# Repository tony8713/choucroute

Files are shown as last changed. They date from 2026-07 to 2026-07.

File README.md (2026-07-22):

# earbox

*l'oreille de la maison* — a 24/7-listening home device that turns ambient
speech into your private, searchable memory, queried through the agent you
already use. **Raw audio never leaves the home.**

Listen → transcribe **locally** → write text into a git-backed memory → ask your
agent about your day over Telegram/WhatsApp. No audio is ever stored or sent.

## Architecture (two-tier)

- **Founder unit (v1): one box** = a **Jetson Orin Nano Super** brain + a
  **reSpeaker XMOS XVF3800** USB 4-mic array (on-chip beamforming/NS/AEC/AGC).
  The mic plugs into the Orin over USB; the Orin transcribes on its GPU with
  **faster-whisper** (CUDA int8) and writes text to a local git memory. **No
  network.**
- **Optional multi-room:** cheap **Pi 4 satellites** stream other rooms to the
  Orin over an **encrypted LAN hop** (TLS). Satellites keep zero storage.

Full design + privacy invariants: `docs/architecture.md`.

## Repo layout

```
orin/        the brain: orind.py (direct XVF3800 OR lan satellite server),
             capture.py (USB mic), stt.py (faster-whisper CUDA / whisper.cpp),
             denoise.py (optional, default-OFF), provision.sh (JetPack 6.x),
             gen_certs.sh, systemd/, config.example.toml
satellite/   optional Pi tier: satellited.py (capture→VAD→opus→TLS, zero
             storage), provision.sh (Pi OS Lite), systemd/, config.example.toml
common/      shared source of truth: earbox_core.py (VAD, cleaning, git memory,
             mute, delete-in-finally), wire.py (LAN protocol+TLS), codec.py
daemon/      summarize.py (text-only egress), query.py, and earboxd.py (the D1
             single-box legacy daemon), harness.py (D1 single-segment harness)
docs/        architecture.md
harness_twotier.py   prove the FULL two-tier plumbing on a Mac (below)
```

## Prove the two-tier plumbing on a Mac (no Pi, no Orin)

`harness_twotier.py` runs the **real** Orin daemon (`orin/orind.py`) in `lan`
mode with real self-signed TLS, then streams a wav through a loopback
"satellite" over the real TLS socket, using the exact wire framing + codec the
Pi uses. The Orin decodes each segment in tmpfs → transcribes → commits to git →
deletes the audio.

```bash
python3 harness_twotier.py scratch/test_fr.wav --seconds 30 --codec pcm
```

It uses the `whisper_cli` STT backend (whisper.cpp, needs `whisper-cli` + a ggml
model on PATH) because faster-whisper needs the Orin's CUDA. So it proves the
whole chain **except** faster-whisper itself, which is benchmarked on the device
(D3). Expect: `TWO-TIER PLUMBING: WORKED`, transcript committed, `stray audio: 0`.

The D1 single-box harness still works too: `cd daemon && python3 harness.py <wav>`.

## Deploy

**Founder unit (Orin + XVF3800), JetPack 6.x:**
```bash
sudo EARBOX_MODE=direct bash orin/provision.sh   # UNTESTED-ON-TARGET (no Orin in dev)
```
Then `arecord -l` to find the reSpeaker card and set `usb_capture_device` /
`usb_asr_channel` in `~/.config/earbox/orin.toml`.

Provision installs the live tree as the **earbox user's own git clone** at
`~earbox/earbox` (with an earbox-owned venv at `~earbox/earbox/venv`) and points
`/opt/earbox` at it via a symlink, so the systemd unit paths still resolve but
the code + venv are user-owned and git-updatable.

### Update the box (no sudo)

Code updates need **no root**. As the `earbox` user on the Orin:
```bash
cd ~/earbox && git pull && earbox-restart
```
`earbox-restart` just kills the daemon (`pkill -f orin/orind.py`); the unit has
`Restart=always`, so systemd relaunches `orind` on the new code in ~3s. No
`sudo rsync` to `/opt`, no `systemctl restart`. (New pip deps: same, just
`~/earbox/venv/bin/pip install ...` as the earbox user.)

### One-time migration (root, only if the box was provisioned the OLD way)

A box already running from a root-owned `/opt/earbox` copy is switched to the
user-repo layout once, with root, then never again:
```bash
sudo systemctl stop orind
sudo mv /opt/earbox /opt/earbox.bak                                   # keep the old copy as backup
sudo -u earbox git clone https://github.com/tony8713/choucroute.git /home/earbox/earbox  # if not already present
sudo -u earbox python3 -m venv /home/earbox/earbox/venv               # earbox-owned venv inside the clone
sudo -u earbox /home/earbox/earbox/venv/bin/pip install --upgrade pip
sudo -u earbox /home/earbox/earbox/venv/bin/pip install faster-whisper zeroconf
sudo ln -sfn /home/earbox/earbox /opt/earbox                          # unit's /opt/earbox/{orin,venv} now resolve into the clone
sudo install -Dm755 /home/earbox/earbox/orin/earbox-restart /usr/local/bin/earbox-restart
sudo systemctl start orind
```
The unit is untouched: `/opt/earbox/orin/orind.py` and
`/opt/earbox/venv/bin/python3` resolve through the symlink into the earbox-owned
clone. After this, every future update is the sudo-free `git pull` above.

**Optional Pi 4 satellite, Pi OS Lite (64-bit):**
```bash
sudo bash orin/provision.sh with EARBOX_MODE=lan on the Orin   # enables the TLS server + certs
sudo bash satellite/provision.sh                               # on the Pi
scp earbox@<orin>:/opt/earbox/tls/orin.crt /opt/earbox/tls/    # pin the Orin cert
# set satellite_id + orin_host (or leave empty for mDNS), then enable the unit
```

## Privacy in one line

Raw audio lives only in tmpfs and is deleted in a `finally` after each segment;
the founder unit opens no network at all; the optional satellite hop is TLS and
LAN-only; only a separate daily **text** summary may ever touch the network. Full
invariant table in `docs/architecture.md` §5.

## Status

Early, local-first, and moving fast. The capture → local-transcribe → git-memory
pipeline is validated end-to-end; the enclosure, fleet, and golden-image work
(D6) are in progress.

## License

MIT — see [LICENSE](LICENSE).

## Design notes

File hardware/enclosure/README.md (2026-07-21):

# earbox — founder-unit enclosure v1 ("le boitier")

Two-chamber tower housing the **NVIDIA Jetson Orin Nano Super Developer Kit**
(lower, vented chamber) and the **Seeed reSpeaker XVF3800 USB 4-mic array**
(upper chamber, kept in its **stock retail case** for v1). Generated with
[text-to-cad](https://github.com/earthtojake/text-to-cad) / build123d.

> **v1 scope:** keep the reSpeaker in its factory case (mic geometry preserved,
> simplest path). A bare-board v2 that reproduces the 66 mm mic square can come
> later. Every model dimension is a named variable at the top of
> `earbox_v1.py`; the acoustically-critical ones are one-line adjustable.

---

## v4 — "le cube" (CURRENT, printable)

Laurent's v4 refinements over v3. Files: `earbox_v4.py`, `earbox_v4.step`,
`earbox_v4.stl`, `preview_v4.png`.

- **Perfect cube** — 114.5 × 114.5 × 114.5 mm (+5 mm feet). Side = smallest the
  round 107 mm case allows while fitting Orin + plenum below the crown.
- **Flat top** — the v3 diagonal summit is gone.
- **Debossed "earbox" fixed** — was upside-down in v3 (`x_dir`/`z_dir` put local
  Y at −Z). Now upright and readable when the cube sits on its feet.
- **Triangles packed closer** — same rounded-triangle quincunx, tighter pitch:
  5×5 facing the Orin fan + a denser underside mesh.
- **No cable channel / clips / hole.** The reSpeaker case seats **rotated 45°**
  so its USB points into the box interior toward the (+X,+Y) corner; the cable
  just drops inside to the Orin. Only a **connector-clearance cutout** at that
  corner (through the cup wall + down through the deck) and a **triangular rim
  marker** on the top show how to orient the case.
- Kept: two-part corner-post pry joint (single solids, nothing captive), case
  **107 × 17 VERIFIED** + **0.75** fits, foam seat, **16 mm** mute hole, 4
  triangular **5 mm feet**, **3 mm** shell, support-light print orientation.

Verified by rendering the exported **STL** (not the sketch): cube, flat top,
upright text, clean rounded-triangle quincunx vents, and the corner cutout.

---

## v3 — "le monolithe vertical" (superseded by v4)

Laurent rejected v2 (vents rendered as hearts/stars; didn't read vertical).
v3 follows his literal spec. Files: `earbox_v3.py`, `earbox_v3.step`,
`earbox_v3.stl`, `preview_v3.png`.

- **Rectangular box, height largest** — 114.5 × 114.5 × **211 mm** (incl. 5 mm
  feet); height is the largest dimension. Orin flat at the bottom, tall plenum,
  reSpeaker crown on top.
- **Shell 3 mm.**
- **Diagonally truncated summit** — two same-side offset 45°-ish planar cuts
  (*deux outils légèrement décalés*) → a stepped/faceted diagonal top.
- **Ventilation = rounded-triangle QUINCONCE** (staggered rows, half-pitch
  offset, alternating up/down, webbed so triangles never touch): a **5×5 grid
  facing the Orin fan** (−X wall, low) + an **underside mesh** (floor intake).
  No other wall perforation. **Built as explicit 3-point polygons with corner
  fillets — not `RegularPolygon`/glyphs** (that + filleting overlapping
  triangles was the v2 hearts/stars bug).
- **4 triangular feet, 5 mm** high, under the corners.
- **"earbox" debossed 2 mm**, monospace (Menlo).

**Kept:** two-part easy-open split; case **107 × 17 VERIFIED**; **0.75 mm** on
all fits; foam-decoupled seat; Orin **30 mm** conservative; **16 mm** mute hole;
support-light orientation.

**The split / openability:** `mono_base` (tall vented body, holds Orin) +
`mono_crown` (truncated cup, holds cased reSpeaker). Four **corner posts** fused
into the base corners locate matching **blind holes** in the crown — 0.75 mm
slip fit. Crown lifts straight off / pries with a fingernail; **nothing captive,
no screws.** Both parts are single watertight solids. Lift crown → base open on
top → drop the Orin in.

**Print orientation (support-light):** `mono_base` upright, open-top up (feet
on the plate, triangle holes + I/O bridge as wall openings); `mono_crown` cup-up
(deck on the plate; cup opens up; the diagonal summit facets step inward =
self-supporting; post holes are shallow bottom pockets).

**Verification:** vents, summit, feet, and text were all confirmed by rendering
the **exported STL** (orthographic outer-skin projections), not the sketch —
the triangles are clean rounded triangles en quinconce, no hearts/stars.

**Same fundamental conflict, resolved:** the round 107 mm case forces a
~114.5 mm footprint in both axes, so "narrow" is read as **proportion** — a
114.5 × 211 tall monolith (ratio 1.84), not a wider box.

---

## v2 — "le monolithe" (superseded by v3)

Laurent rejected v1 as *"batiment antique"* (too temple-like). v2 adopts his
design language. Files: `earbox_v2.py`, `earbox_v2.step`, `earbox_v2.stl`,
`preview_v2.png`.

**Design language (Laurent):**
- **Vertical monolith** — 128.5 × 128.5 × 184 mm, height:width ≈ **1.43** (v1
  was 0.56, a squat tower). Tall exhaust-plenum body over the Orin chamber.
- **Sommet tronqué sur deux arêtes** — the two top edges (‖ X) are truncated
  with 45° planar cuts (8 mm), a chiselled crown; the round mic opening sits in
  the middle of it.
- **Triangle-mesh ventilation** — tessellated up/down rounded triangles (11 mm
  side, 1.3 mm corner radius, 4 mm webs) instead of slots: floor intake + a high
  panel on all four walls (exhaust + the signature texture).

**Verified dims used:** reSpeaker case **107 mm × 17 mm** (caliper). Orin stack
height stays the conservative **30 mm** (still unverified).

**FDM fits (Laurent's 2am rule): 0.75 mm on ALL fits** — cup seat (Ø108.5 ID
around the 107 case, foam-lined), Orin chamber (generous), and the two-part
joint. Loose is shimmable with foam; tight is a trash print.

**Openability — the split (hard requirement):**
- **Two parts:** `mono_base` (tall vented body, holds the Orin) and
  `mono_crown` (truncated cup block, holds the cased reSpeaker).
- **Joint:** the base has an upstanding **locating spigot** (fused to the wall);
  the crown has a matching **groove** in its underside. The crown drops on and
  **lifts straight off** — 0.75 mm slip fit, pry with a fingernail, **nothing
  captive, no screws.** Both are single watertight solids.
- **Access:** lift the crown → the base is open on top → drop the Orin in (or
  out). The reSpeaker drops into the crown cup from the top. Fully serviceable.

**Print orientation (support-light):**
- `mono_base`: **upright, open-top up.** Vertical walls; the triangle holes and
  I/O windows bridge as wall openings; floor solid on the plate. No supports.
- `mono_crown`: **cup-up, deck on the plate.** Cup cavity opens upward (no
  support); the two 45° truncation facets step *inward* going up (self-
  supporting); the joint groove is a shallow bottom pocket (a few-mm bridge).

**Design-language conflicts and how they were resolved:**
1. *Deep two-edge truncation vs. a near-full-width mic cup.* The 107 mm case
   leaves almost no wall at the footprint edges, so a large bevel would breach
   the cup. **Resolved** by adding a 7 mm solid **joint frame** around the cup
   (footprint grows to 128.5), giving real material for both the bevel and the
   pry joint — at the cost of some slimness, recovered via **height** (1.43
   ratio). The 8 mm bevel now lives in the frame.
2. *"Slender footprint" vs. the round 107 mm cup.* A truly slim footprint is
   impossible while the cased mic sits on top. **Resolved** by reading "vertical"
   as **proportion, not plan area**: constant clean cross-section, tall body,
   truncated crown — a monolith, not a mushroom (no overhang, which would re-read
   as temple/pedestal).
3. *OCC chamfer failed at the rounded corners; pending-face extrude dropped the
   triangle sketch.* Engineering, not design: truncation done with **planar
   splits**, triangle panels extruded from an **explicit sketch**. Spigot made to
   **overlap** the wall so the base stays one fused solid.

Open items for Laurent are unchanged below (foam thickness/material, Orin stack
height, PSU — external **60 W barrel brick confirmed**, base↔crown retention if
the pry fit is too loose/tight after measuring).

## Files

| File | What |
| --- | --- |
| `earbox_v1.py` | Parametric build123d source. `gen_step()` returns the 2-part assembly (`orin_base` + `mic_tower`). |
| `earbox_v1.step` | Primary CAD artifact (assembly). |
| `earbox_v1.stl` | Printable mesh sidecar. |
| `foam_gasket.py` | 2D generator for the laser-cut foam decoupling ring. |
| `foam_gasket.dxf` | Laser-cut layout for Laurent (foam). |
| `preview.png` | Isometric preview render. |

Regenerate after editing dims:

```bash
# from tools/text-to-cad with its venv active, run against this dir
python skills/cad/scripts/step /Users/tony/work/earbox/hardware/enclosure/earbox_v1.py \
  --stl /Users/tony/work/earbox/hardware/enclosure/earbox_v1.stl
# or standalone: python earbox_v1.py  (writes earbox_v1.step)
python foam_gasket.py
```

## Architecture

```
            ___________________            <- reSpeaker mics face up, ~6 mm proud
           /   reSpeaker case  \           <- STOCK retail case (kept intact)
          | [ ]  mic  puck  [ ] |          <- LED ring band recessed near rim
          |=== foam gasket ring ===|       <- ONLY load path (laser-cut foam)
       ___|_______ deck __________|___     <- SOLID deck: isolates fan noise
      |    |  cable channel (USB)  |   |    <- one 9 mm pass-through, deck solid elsewhere
      |    +-------------------+    |  <-- mute switch hole (privacy) on cup wall
      |     Jetson Orin Nano Super   |
      |  [====== fan / heatsink ===] |     <- exhaust vents on 3 side walls (high)
      | O O   standoffs lift board   |     <- intake vents in the floor
      |__[I/O ports: DP USB USB RJ45 USB-C DC]__|  <- +Y long wall
```

- **Two chambers, acoustically decoupled.** The cased reSpeaker rests only on a
  laser-cut **foam gasket ring** seated in a recess in the cup floor; there is
  radial clearance (`RESPEAKER_RADIAL_CLEAR`, 1 mm) between the case and the cup
  wall, so there is **no rigid path** from the mic case to the chassis. The deck
  under the gasket is **solid** (except the cable channel), so the Orin fan's
  airborne noise is blocked from the mic chamber and the foam breaks the
  vibration path.
- **Real airflow for the Orin.** Intake slots in the floor (cool air drawn up
  under the lifted board), exhaust slots high on three side walls. `ORIN_LIFT`
  (4 mm) standoffs create an underside plenum. Nothing sits directly over the
  fan; `ORIN_TOP_CLEAR` (8 mm) leaves head-room above the fan to the deck.
- **Cable channel.** A single 9 mm channel through the deck routes the USB-C
  from the reSpeaker down to a USB-A port on the Orin.
- **I/O openings** on the +Y long wall: DisplayPort, 2× USB-A (double stack),
  RJ45, USB-C, DC barrel jack. The board registers against this wall so
  connectors align with the windows.
- **Privacy mute switch** hole on the cup wall (7 mm, panel-mount).
- **LED ring band**: shallow external recess near the cup's top rim where
  Fabien's trust-interface LED ring can later seat (depth < wall, non-breaching).

## Dimensions — VERIFIED vs UNVERIFIED

Per Laurent/Iris: online reSpeaker case dims diverge, so **every reSpeaker case
value below is UNVERIFIED and must be caliper-checked (or measured from Seeed's
official STEP) before printing.** VERIFIED = official datasheet/spec.

### Jetson Orin Nano Super Dev Kit (P3768 reference carrier)

| Dim | Value | Status | Source |
| --- | --- | --- | --- |
| Board L × W | 100 × 79 mm | **VERIFIED** | NVIDIA Orin Nano Dev Kit datasheet |
| Assembled height (incl. thermal) | **30 mm used** (datasheet says 21 mm "incl. feet, carrier, module, thermal"; jetsonhacks quotes 30 mm) | **UNVERIFIED / conflict** | NVIDIA datasheet vs jetsonhacks — we default to the larger 30 mm so the fan is never choked. Caliper the real Super fan; if ~21 mm set `ORIN_HEIGHT=21`. |
| DC barrel jack | 5.5 mm OD / 2.5 mm ID, centre-positive | **VERIFIED** | NVIDIA hardware_layout |
| USB-C (data) | 1× | **VERIFIED** | NVIDIA hardware_layout |
| I/O all on one long edge | DP → 2× USB-A stack (4 ports) → RJ45 → USB-C → DC jack | edge **VERIFIED** (photos); exact left→right order **UNVERIFIED** | NVIDIA hardware_layout + product photos |
| 40-pin GPIO header | opposite long edge | **UNVERIFIED** (standard P3768) | — |
| microSD | on the module underside | **VERIFIED** | NVIDIA callout |
| Mounting-hole pattern | not published | **UNVERIFIED** | pull from NVIDIA STEP or measure |
| Fan airflow | top axial fan, blows **down** through fins, exhausts laterally | type **VERIFIED**, vector **UNVERIFIED** | assembly type |

### Seeed reSpeaker XVF3800 (retail, in stock case)

| Dim | Value | Status | Source |
| --- | --- | --- | --- |
| PCB shape | circular | **VERIFIED** | Seeed wiki / product page |
| Bare PCB diameter | ~99 mm (× 4 mm thick) | **UNVERIFIED** | cnx-software (third-party) — note: brief said ~70 mm, actual is ~99 mm |
| Stock case outer diameter | **107 mm** | **VERIFIED** | Laurent caliper 2026-07-22 |
| Stock case height | **17 mm** | **VERIFIED** | Laurent caliper 2026-07-22 |
| Case shape | round | **VERIFIED** (shape only) | Seeed p-6490 page |
| Mic array geometry | 4 mics on a 66 mm square (diag ~93.3 mm, radius ~46.7 mm) | **VERIFIED** | Seeed wiki mic coordinates |
| USB | USB-C (UAC 2.0); 2nd USB-C for firmware | **VERIFIED** | Seeed wiki |
| Case SKU | with-case = p-6490 (base p-6488 is bare board) | **VERIFIED** | Seeed product pages |
| Mounting holes | not published | **UNVERIFIED** | measure STEP |

## Derived enclosure envelope (at current defaults)

| Quantity | Value |
| --- | --- |
| Base outer (L × W × H) | 111 × 110 × 45 mm |
| Mic tower (dia × H) | 110 mm × 17 mm |
| Overall height (base + tower + case proud) | ~68 mm |
| Wall / deck thickness | 3.0 mm |
| Cup inner dia (case + 2×clearance) | 104 mm |
| Foam gasket ring | OD 104 / ID 92 mm |

> The cased mic puck (~110 mm) is wider than the bare Orin footprint (~90 mm),
> so the base is grown to fully support the puck; the extra interior around the
> board is air plenum (helps, does not choke, the fan).

## Print notes

- FDM, 3 mm walls, no heroic supports intended. Print the **two parts
  separately**, each open-side-down:
  - `orin_base`: print floor-down; port windows and side vents print as wall
    openings (bridged), no supports needed.
  - `mic_tower`: print deck-down (cup opening up); the cup is a simple upward
    cavity — no supports. The LED band and mute hole are shallow/side features.
- Suggested: 0.2 mm layers, 3–4 perimeters, 20–30% infill (PETG or ASA for
  heat near the Jetson; PLA fine for a bench mock-up).
- Cable channel and mute hole may need a light chamfer/ream after printing.
- The two parts are a clearance stack in v1 (tower sits on the base rim). Add
  screw bosses / a lip catch in v2 once real parts are calipered.

## Foam gasket spec (for Laurent)

- **Part:** flat annular ring, laser-cut from foam.
- **OD:** 104 mm (= cup inner diameter; `CUP_INNER_DIA`).
- **ID:** 92 mm (open window under the mics; `FOAM_SEAT_INNER_DIA`).
- **Thickness:** **3 mm assumed — please confirm** (`FOAM_THICKNESS`). This sets
  both the gasket-seat recess depth and the mic stand-off, so the CAD updates
  with whatever foam stock you pick.
- **Material:** soft closed-cell (EVA / PORON / EPDM) for damping; final
  durometer your call.
- Layout: `foam_gasket.dxf`.

## Open questions for Laurent

1. **Foam thickness / material** for the gasket (drives seat depth + standoff).
2. **Real Orin Super stack height** incl. fan — 21 mm (datasheet) or ~30 mm
   (measured)? Sets `ORIN_HEIGHT` and the whole lower-chamber height.
3. **reSpeaker stock case** real OD + height (caliper) — sets the cup.
4. **PSU strategy:** barrel-jack brick external, or integrate a DC supply inside
   the base? v1 assumes external brick, barrel jack only.
5. Mounting: screw bosses vs clip lip between base and tower for v2.

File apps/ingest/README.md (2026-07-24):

# @choucroute/ingest — Fly audio-ingest API

A small Bun WebSocket server that accepts a **live binary audio stream** from the
earbox and measures it, exposing a clean seam where cloud STT (Parakeet/Canary on
a GPU) attaches next. Deployed on Fly.io in **region `sin`** (Singapore — closest
to the box in Thailand, UTC+7).

This reverses the earlier "audio never leaves the box" model. That is a deliberate
product decision (Less, 2026-07-23). The **irreversible flip of pointing the real
box at this endpoint is still pending Less + Laurent alignment** — this repo ships
the plumbing and a local/test client proof only; do not auto-start the box streamer
against prod.

## Audio format (the wire contract)

Raw **PCM S16LE, 16 kHz, mono** — exactly what `orin/capture.py` produces. Binary
WS frames of raw PCM, ~100 ms each (3200 bytes). Continuous 16k PCM ≈ **256 kbps**;
Opus would cut that ~10x and is the obvious next optimization (the box already has
`opusenc`; see `common/codec.py`). Start with PCM for simplicity.

## Endpoints

- `GET /health` → `{ status, uptimeSeconds, openConnections, totalConnections, format }`
- `WS /ingest` → live PCM stream. On connect the server sends
  `{ type: "hello", streamId, format }`, then periodic
  `{ type: "ack", bytes, samples, audioSeconds, wallSeconds, chunks, gaps }`
  every `ACK_INTERVAL_MS`. Send a text `{ "type": "ping" }` for an immediate
  `pong` snapshot. Binary frames are the audio.

## Server behavior (MVP)

- Authenticates the connection (see Auth), assigns a `streamId`, tracks stats
  (bytes, samples, audio vs wall seconds, chunk count, gap detection).
- Feeds every chunk to an `AudioSink` (`src/sink.ts`) — **this is the STT seam**.
  The default `MeasuringSink` only measures. Swapping in a real STT sink is a
  drop-in: implement `AudioSink.write(chunk)` / `close()` and pass a `SinkFactory`
  to `createServer(config, sinkFactory)`.
- Keeps only an **in-memory rolling buffer** (`ROLLING_BUFFER_SECONDS`, default 30s).
  **Never writes audio to disk** (`PERSIST_DIR` empty by default — a privacy
  invariant, matching the box's tmpfs-only rule).

## Auth — deferred, not removed

Per Less ("no auth for now", 2026-07-23) and the Iris security review: the
bearer / `?token=` check ships **present in the code** but **gated off by default**
(`AUTH_ENABLED=0`). Re-enabling is a one-line flag flip plus a secret, no rebuild:

```sh
fly secrets set STREAM_TOKEN=$(openssl rand -hex 32) --app earbox-ingest
fly secrets set AUTH_ENABLED=1 --app earbox-ingest
```

Then clients must present `?token=<t>` or `Authorization: Bearer <t>`. A public
unauthenticated live-audio endpoint is a known hole for a confidentiality-critical
product — turn this on before any non-test use.

## Run locally

```sh
bun install
bun run --filter @choucroute/ingest dev        # or: cd apps/ingest && bun run dev
curl localhost:8080/health
# stream a wav through it (REALTIME=0 = as fast as possible):
REALTIME=0 bun apps/ingest/scripts/stream-file.ts ws://localhost:8080/ingest scratch/long_fr.wav
```

## Deploy (Fly)

```sh
cd apps/ingest
fly apps create earbox-ingest --org snack-labs   # once
fly deploy --ha=false --now
fly status --app earbox-ingest
```

Single always-on `shared-cpu-1x` / 512 MB machine in `sin`, WebSocket over the
standard Fly HTTPS handler (`internal_port = 8080`, `force_https = true`).
Live endpoint: `wss://earbox-ingest.fly.dev/ingest`.

## Box streamer

See `orin/stream.py` (captures the reSpeaker Array, streams PCM16 16k mono here
with reconnect + mute-flag coordination). It opens the **same ALSA device orind
holds exclusively**, so it cannot run alongside prod orind — stop orind (or set
the mute flag) first. Run command is documented in that file's header.

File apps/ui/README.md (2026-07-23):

# @choucroute/ui

A simple web timeline for monitoring every transcription the box produces:
a reverse-chronological feed grouped by day, with full-text search, a date range,
and per-room filters. Built with the real `@stage-labs/kit` (the Stage design
system's React Native component family) rendered on the web via
`react-native-web`, so it matches the Stage / Snapshot design language. The
feed shows sample data by default; a remote source is opt-in via
`VITE_TRANSCRIPTS_URL`.

```
bun install
bun run --filter @choucroute/ui dev     # http://localhost:5175
```

Out of the box it renders fabricated sample transcripts (`src/data/mock.ts`) so it
runs with zero setup.

## Pointing at real transcripts

Real transcripts live in the **private** `earbox-memory` repo as day-keyed
markdown (`transcripts/YYYY-MM-DD.md`) and contain personal data — they are never
committed here. The UI reads from a configurable source instead:

Set `VITE_TRANSCRIPTS_URL` (copy `.env.example` to `.env.local`) to a URL that
returns either:

- **markdown** — one or more day files concatenated, in the box's native format
  (`# YYYY-MM-DD` headers, `- **HH:MM** _(room)_ text` lines), or
- **JSON** (`content-type: application/json`) — an array of
  `{ day, time, timestamp, room, text }` entries.

Two easy ways to serve the private memory locally:

```
# static: serve the memory repo, bundle the day files, point the UI at it
cd /path/to/earbox-memory && python -m http.server 8099
# then VITE_TRANSCRIPTS_URL=http://localhost:8099/transcripts/2026-07-22.md

# or expose your own private read-only API returning the JSON shape above
```

No audio and no real transcript text is ever stored in this repo.

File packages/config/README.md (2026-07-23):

# @choucroute/config

Shared ESLint, TypeScript and madge presets for the choucroute monorepo. Mirrors
the setup of [`@stage-labs/config`](https://github.com/bonustrack/stage) so the JS
workspaces here follow the same house style: strict type-checked lint, single
quotes, banned comments, 400-line file cap, 100-line function cap.

## Usage

Workspaces are declared in the repo-root `choucroute.config.js` via `defineConfig`.
The `choucroute` CLI reads it:

```
choucroute lint       # eslint across every workspace
choucroute typecheck  # tsc --noEmit per workspace
choucroute madge      # circular-dependency check
```

Each workspace extends the shared TS base:

```json
{ "extends": "@choucroute/config/tsconfig/base.json" }
```

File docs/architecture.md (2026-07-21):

# earbox — architecture

*"l'oreille de la maison"* — a 24/7-listening home device that turns ambient
speech into the owner's private, searchable memory, queried through the agent
they already use. **Raw audio never leaves the home.**

## 0. What changed since D1

D1 was a single-box Raspberry Pi 5 running whisper.cpp on CPU. D2 locks a
**two-tier** design and a more capable brain:

- **The brain is a Jetson Orin Nano Super.** STT is **faster-whisper**
  (CTranslate2) on the Orin **GPU** (CUDA, int8), not CPU whisper.cpp. This buys
  headroom for larger models and multiple mics.
- **The founder unit is ONE box: Orin + a reSpeaker XMOS XVF3800 USB 4-mic
  array.** The XVF3800 does beamforming, noise suppression, AEC and AGC
  *on-chip* and plugs straight into the Orin over USB. **No Pi. No LAN hop.**
  This is v1.
- **The Pi 4 satellite tier stays, demoted to an OPTIONAL multi-room
  extension.** A cheap Pi in another room streams that room to the Orin over an
  encrypted LAN hop. Not needed for the founder unit.

Privacy invariants are unchanged. The Pi→Orin hop (when used) is LAN-only and
encrypted; nothing audio ever touches the internet.

## 1. Topology

```
 FOUNDER UNIT (v1, single box, no network):

   reSpeaker XVF3800 ──USB──▶┌──────────────── Jetson Orin Nano Super ─────────────────┐
   (4-mic, on-chip DSP:      │  capture (ALSA, processed ASR channel)                   │
    beamform/NS/AEC/AGC)     │     │                                                     │
                             │     ▼   raw audio in tmpfs (/dev/shm) — DELETED per seg   │
   physical mute ───────────▶│   VAD gate ─▶ [denoise: BYPASS] ─▶ faster-whisper (CUDA   │
                             │                                     int8, small/medium)  │
                             │                       │                                   │
                             │                       ▼   git commit (earbox-memory)      │
                             │                  transcript text ─────────┐               │
                             └───────────────────────────────────────────┼──────────────┘
                                                                          │ TEXT ONLY
                                       daily summary (summarize.py) ──────┘
                                                     ▼
                                     owner's agent ◀── Metro (Telegram/WhatsApp/…)

 OPTIONAL MULTI-ROOM (satellite tier):

   Pi 4 + mic ──▶ VAD gate ──▶ opus encode ──▶ TLS/LAN ──▶ Orin (same pipeline above)
   (bedroom)      zero storage on the Pi; audio deleted right after streaming
```

## 2. Components

### Orin brain — `orin/`
- **`orind.py`** — the brain daemon. Two input modes feed **one** pipeline:
  - `direct` (PRIMARY): capture the local XVF3800 over ALSA. No network.
  - `lan` (OPTIONAL): a TLS server; satellites stream encrypted segments in.
  - Pipeline: VAD (`common`) → **denoise (bypass by default)** → STT backend →
    `clean_transcript` → append to git memory tagged with the source room →
    **delete the raw audio in a `finally`**.
- **`capture.py`** — direct USB capture from the XVF3800. It exposes several
  channels; we feed whisper the **DSP-processed ASR channel** (post
  beamforming/NS/AEC/AGC), *not* the raw per-mic channels. Device + channel
  index are config (`usb_capture_device`, `usb_channels`, `usb_asr_channel`) and
  **must be confirmed on-device** against the reSpeaker XVF3800 docs (D3).
- **`stt.py`** — STT backends: `faster_whisper` (CUDA int8, production),
  `whisper_cli` (whisper.cpp — the D1 path, runs on a Mac, used by the harness),
  `echo` (plumbing).
- **`denoise.py`** — the **optional, default-OFF** pre-processing stage. The
  XVF3800 already denoises on-chip, so software denoise defaults off. It stays
  pluggable for the raw-mic satellite path and for **Laurent's chain (name
  PENDING)**: set `denoise_cmd` (wav-in/wav-out) or replace `_builtin_denoise`.
- **`provision.sh`** — JetPack 6.x: venv + faster-whisper, install code, tmpfs
  scratch, TLS certs (lan mode), memory repo, systemd. **UNTESTED-ON-TARGET.**

### Pi satellite — `satellite/` (optional)
- **`satellited.py`** — mic capture (`arecord`) → VAD gate → opus/pcm encode →
  stream to the Orin over TLS. **Zero storage on the Pi**: every wav is deleted
  right after it is sent (or skipped). No transcripts, no memory on the Pi.
- **`provision.sh`** — Pi OS Lite (64-bit): install code, opus-tools, zeroconf,
  tmpfs scratch, systemd. The Orin's `orin.crt` is copied here as the pinned CA.

### Shared — `common/`
- **`earbox_core.py`** — the single source of truth for the privacy-critical
  pieces (VAD, `clean_transcript`, git memory, mute, the delete-in-`finally`
  `process_segment`). Both tiers import it so the logic can't drift. Refactored
  out of the D1 `earboxd.py`.
- **`wire.py`** — the LAN hop protocol: a JSON header + length-prefixed frames
  over TLS. Server/client TLS context helpers.
- **`codec.py`** — per-segment encode/decode: `pcm` (zero-dep WAV bytes) or
  `opus` (Ogg/Opus via opus-tools).

### Egress / query — `daemon/` (reused from D1)
- **`summarize.py`** — the only networked component: reads the day's *text*,
  asks the owner's agent to summarize, writes it back, optionally notifies via
  Metro. Parsimony-gated (at most one digest/day, silent if nothing notable).
- **`query.py`** — local read-only search over the markdown. In production the
  owner just asks their agent, which reads the same repo.
- **`earboxd.py`** — the D1 single-box (Pi 5 + whisper.cpp) all-in-one daemon,
  kept as a legacy/reference path. Superseded by the Orin `direct` mode.

## 3. Discovery / pairing (satellite tier)

- The Orin advertises `_earbox._tcp` over **mDNS** (`orind.py` `_advertise_mdns`,
  python `zeroconf`; falls back to a static host if unavailable).
- A satellite either points at a static `orin_host` or mDNS-discovers the Orin.
- The LAN hop is **TLS** with a **self-signed cert** the satellite pins
  (`tls_cafile` = the Orin's `orin.crt`). `gen_certs.sh` mints it. A PSK/mutual
  scheme is a drop-in alternative.
- **PRODUCTION HARDENING TODO:** run the hop inside **WireGuard** and/or move to
  **mutual-TLS with per-satellite client certs** and hostname pinning. The
  self-signed-only path is fine for a trusted home LAN, not for untrusted ones.

## 4. Dataflow (one segment)

1. Muted? → skip (mic never opened).
2. Capture 30s to **tmpfs** (`/dev/shm/earbox`) — RAM, never the SSD/SD.
   - founder: Orin captures the XVF3800 processed channel.
   - satellite: Pi captures its mic, VAD-gates, opus-encodes, streams over TLS;
     the Orin decodes the segment back to a tmpfs wav.
3. VAD: silent? → delete wav, done.
4. Denoise stage: **bypass by default** (XVF3800 did DSP). Optional plug.
5. faster-whisper (CUDA int8) transcribes → text; hallucination/silence filtered.
6. Non-empty text → append to `transcripts/YYYY-MM-DD.md` tagged `_(room)_`,
   `git commit`.
7. **`finally`: delete the wav.** Audio is destroyed whether or not 4–6
   succeeded. This is in a `finally` by design, in `common.process_segment`.

## 5. Privacy invariants (the product promise)

| # | Invariant | How it is enforced |
|---|---|---|
| 1 | Raw audio never leaves the **home** | Founder unit: the Orin captures locally and (mode=direct) opens **no socket at all**. Satellite hop is **LAN-only and TLS-encrypted**; the Orin binds a private LAN address, never a public one. Nothing audio is ever addressed to the internet. |
| 2 | No audio at rest | Scratch is tmpfs (`/dev/shm`, `noexec,nosuid`); every segment deleted in a `finally`; the Pi keeps **zero** storage; `keep_debug_audio` guarded off; `.gitignore` bans audio extensions. |
| 3 | Physical mute | GPIO switch (or `~/.earbox-muted` flag) checked before each capture; muted = mic never opened. |
| 4 | Transcripts stay local | git repo on the Orin; no remote configured by default. |
| 5 | Text-only egress | Only `summarize.py` touches the network; it reads markdown, never audio; runs as a separate unit on a timer. |
| 6 | Parsimony | Device speaks at most once/day, only if the summary is non-empty. |

**Honest note on invariant #1 vs D1:** the D1 Pi-5 capture daemon ran with
`PrivateNetwork=yes` (no network namespace — it *physically* could not
transmit). The Orin brain cannot do that in `lan` mode (it must accept the
satellite socket) and the summary step needs egress. So on the Orin the promise
is enforced by *what the code sends* (only tmpfs-scoped audio that is deleted;
only text committed/egressed), not by a kernel namespace. In `direct` mode the
Orin opens no socket, which is the strongest configuration and the founder
default. Iris's D5 protocol must make this un-footgunnable (asserted at boot).

## 6. Hardware decisions

### Why the Orin (brain), not a Pi 5
The Pi 5 (D1) transcribes **base** at ≈1× real time on CPU — no headroom for
larger models, denoise, or multiple rooms, and it throttles under 24/7 load. The
**Jetson Orin Nano Super** has a CUDA GPU; **faster-whisper small/medium int8**
is *expected* to run comfortably faster than real time there, which is what lets
one box serve good WER plus (optionally) several satellites.

> **This number is NOT yet measured.** There is no Orin in the dev environment.
> All Orin-specific code (`faster_whisper` backend, `capture.py`, `provision.sh`)
> is **UNTESTED-ON-TARGET** and marked as such. The small-vs-medium int8 RTF, in
> **real kitchen noise**, MUST be benchmarked on the device on **D3**.

### Why the XVF3800 (mic), and why software denoise is off
The reSpeaker **XMOS XVF3800** is a 4-mic USB array with **on-chip** beamforming,
noise suppression, AEC and AGC. It plugs directly into the Orin over USB and
enumerates as a standard USB audio class device, collapsing the founder unit to
a single enclosure with no satellite. Because the DSP is on-chip, the software
`denoise` stage **defaults to bypass** — stacking a second denoiser on already
cleaned audio usually *raises* WER. The stage stays pluggable for the raw-mic
satellite path and for Laurent's chain.

> **UNTESTED-ON-TARGET:** the XVF3800 channel layout (which output channel is the
> processed ASR mono) is firmware-dependent and must be confirmed with
> `arecord -l`/`-L` on the real device (D3). `usb_asr_channel` defaults to 0.

### Hailo — excluded for STT (correctly)
If a Hailo module is present on the carrier, note it is a **vision/CNN
accelerator** (INT8 conv nets — detection/classification). It does **not** run
Whisper's transformer encoder/decoder; there is no supported faster-whisper /
CTranslate2 path on Hailo. STT stays on the **Orin GPU via faster-whisper CUDA**.
Hailo is only relevant if we later add on-device vision, which is out of scope.

## 7. Sizing / gotchas
- **Storage (sprint): SD-only.** The founder Orin runs entirely from the 128GB
  microSD (~95GB free — ample for the OS, the faster-whisper model cache, and the
  text-only git memory). There is **no NVMe `/data` mount** for the sprint: the
  rover NVMe was removed and shelved (restoration guaranteed later, no data loss).
  An NVMe at `/data` is **optional**: `orin/provision.sh` resolves a `STORAGE_ROOT`
  that defaults to the service user's home on the SD and uses `/data` only if it
  is actually mounted (`EARBOX_DATA=<path>` overrides). Memory repo, models dir,
  and the systemd `ReadWritePaths` are all derived from `STORAGE_ROOT`, so moving
  to an NVMe later is a one-variable change, not a rewrite.
- **Benchmark faster-whisper small vs medium int8 on the Orin (D3)** under
  thermal load and in kitchen noise; pin whichever holds real time.
- CTranslate2 on JetPack must be a **CUDA aarch64** build; the stock PyPI wheel
  may be CPU/desktop-CUDA only. Verify `device=cuda` works on-device or build
  from source. (Noted in `provision.sh`.)
- tmpfs scratch sized small (64–128M) — segments are ~1MB each at 16kHz mono.
- Language pinned (`fr`) is faster than `auto`; `auto` misdetects short chunks.
- Active cooling for 24/7 inference on the Orin.
- Chunk-boundary word cuts (fixed 30s) still apply — VAD-aligned segmentation is
  the fix (carried from D1 risks).

## 8. Seven-day plan

- **D1 (done):** repo + buildable single-box skeleton; pipeline validated on the
  Mac harness (chunk → VAD → whisper → git commit → audio deleted, 0 stray).
- **D2 (done):** two-tier restructure — `orin/` brain (direct XVF3800 + optional
  LAN server; faster-whisper CUDA backend; denoise-bypass plug; git memory;
  delete-in-finally), `satellite/` Pi tier (capture→VAD→opus→TLS, zero storage),
  `common/` shared core + wire + codec, mDNS + self-signed TLS pairing,
  provisioning + systemd for both. **Mac two-tier harness proves the full
  plumbing end-to-end** (loopback satellite → real TLS → Orin daemon → real
  transcription → git → audio destroyed).
- **D3:** **on-Orin benchmark** — flash JetPack 6.x, run `provision.sh`, get
  faster-whisper on CUDA, measure **small vs medium int8 RTF in real kitchen
  noise** with the **XVF3800** as the mic (confirm the ASR channel with
  `arecord`); tune VAD + segment length to the array; confirm thermals under
  24/7 load. Real Pi-4 satellite as a stretch.
- **D4:** Metro/agent query integration — owner asks their agent and it reads
  `earbox-memory`; wire `summarize.py`'s `EARBOX_SUMMARY_CMD`/`EARBOX_NOTIFY_CMD`
  to the agent + Metro channel.
- **D5:** physical mute switch (GPIO) + state LED/display; parsimony tuning
  (only-speak-when-real); land **Iris's privacy protocol** as a written,
  testable checklist mapped to the invariants above (incl. the Orin invariant-#1
  nuance from §5).
- **D6:** assembly + golden images — Orin+XVF3800 enclosure; `dd`/`rpi-image-gen`
  for the (optional) satellite; per-unit identity + owner memory bootstrap;
  first-boot config wizard.
- **D7:** demo (speak → query over Telegram); preorder page; pricing.

## 9. Top risks (honest)

1. **faster-whisper RTF on the Orin is unproven here.** small/medium int8 is
   *expected* faster-than-real-time but is **not measured** — no Orin in dev.
   D3 must confirm it (in kitchen noise, under thermal load) or we drop model
   size / shorten segments.
2. **CTranslate2 CUDA on JetPack is a known packaging hazard** — the wheel may
   not be a Jetson CUDA build; may need a source build on-device.
3. **XVF3800 channel layout is firmware-dependent** — feeding whisper the wrong
   (raw) channel would tank WER. Confirm the ASR channel on-device.
4. **LAN hop trust.** Self-signed-pinned TLS is fine on a trusted home LAN; an
   untrusted LAN needs WireGuard/mutual-TLS (hardening TODO). The founder unit
   sidesteps this entirely (no hop).
5. **Orin invariant-#1 is code-enforced, not namespace-enforced** (see §5). Needs
   Iris's boot-time asserts so a misconfig can't leak.
6. **Whisper hallucination on ambient noise/music** — filter list + VAD help but
   aren't perfect.
7. **Always-on mic in a home is a consent/legal surface** (bystanders, other
   members, jurisdictions). Product + legal, not just tech.
8. **A private git remote is still needed for the team.** Everything is
   local-first and unpushed; we need a private remote before D6 fleet work.

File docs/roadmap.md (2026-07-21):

# earbox — roadmap & ideas

Running log of agreed decisions and parked ideas so they don't get lost between
threads. Newest first. See `docs/architecture.md` for the settled design.

## Love-first easter egg — heartbeat LED (Laurent)

If the owner says **"je t'aime"** to the box, the LED ring plays a **heartbeat
pulse**. The phrase is matched **locally in the transcript** — nothing about it
ever leaves the device.

The point isn't cute: the easter egg **doubles as a live privacy proof**. The
heartbeat can only ever happen if the machine understood the phrase *on-device*.
A box that phoned home wouldn't light up on the same words with the network
pulled. So the gesture is also the demo.

## Audio never on disk

**Invariant:** raw audio is transient and must never durably land on the SD card.

- **v1 (quick win):** point the audio chunk temp dir at **tmpfs (`/dev/shm`)** so
  chunks live in RAM and never touch the SD card. Keep the existing
  **delete-in-`finally`** as a backstop — belt and suspenders.
- **v1.1 (target):** **full in-memory streaming** — no temp file at all, chunks
  handed straight from capture to STT.

## v1 UI decision

**No screen. LED ring only.** DisplayPort is reserved for **workshop debug**, not
an owner-facing surface.

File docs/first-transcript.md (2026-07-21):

# earbox — the first live transcript

**2026-07-22, ~04:59 workshop time.**

The first end-to-end live transcription happened here. Real speech into the
**reSpeaker XVF3800** 4-mic array, over USB into the **Jetson Orin Nano Super**,
through **faster-whisper** (CPU, int8, `small`) running fully **on-device**, out
to text. **The audio was deleted by construction** — transient in tmpfs,
never durably written, exactly as the privacy invariant demands. This is the
first time the whole chain carried live voice, not a canned wav.

The hard part wasn't the model. The mic read as a dead signal — silence where
speech should be — and the culprit was a **USB-A→USB-C adapter** in the path.
Swapped it for a **known-good cable** and the array came alive on the first try.

## The transcript

```
[0.00  -> 24.77] C'est bizarre de chier dans la choucroute.
[24.77 -> 31.65] Même les chats chient dans la choucroute, ce qui est très bizarre.
[36.33 -> 40.33] C'est bizarre à 4h59 de chier dans la choucroute.
[40.33 -> 49.48] C'est très bizarre à 5h du matin de chier dans la choucroute.
[49.48 -> 60.01] C'est bizarre de chier dans la choucroute si tôt le matin.
```

The improvised time references in the speech — *"à 4h59"*, *"à 5h du matin"* —
match the wall clock at recording. That's the proof it was **live**: the model
transcribed words spoken in the room at that minute, not a replay.

## Performance

**60 s of audio transcribed in ~16 s** on the Orin CPU (faster-whisper, int8,
`small`). Real-time factor well under 1× before the GPU is even in the picture —
CUDA int8 is the headroom, this was the floor.

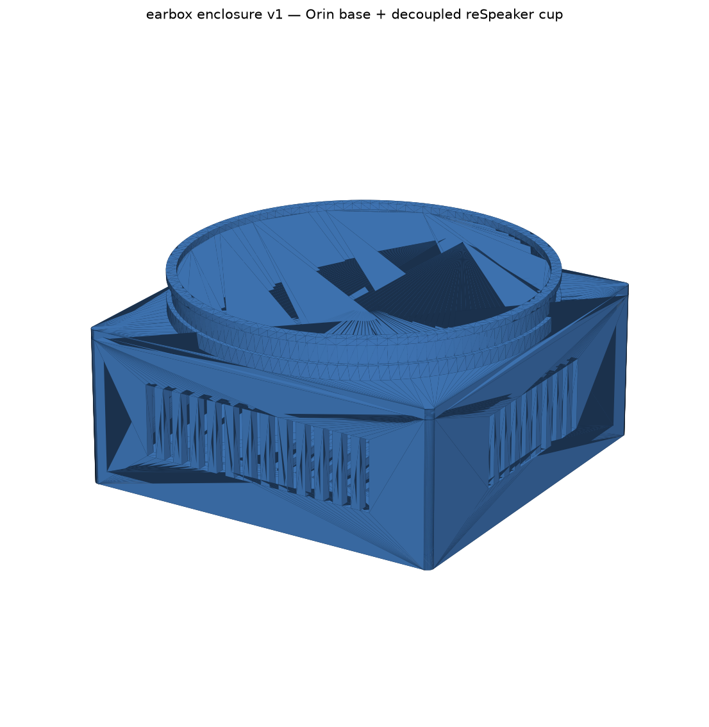
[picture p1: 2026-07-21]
hardware/enclosure/preview.png

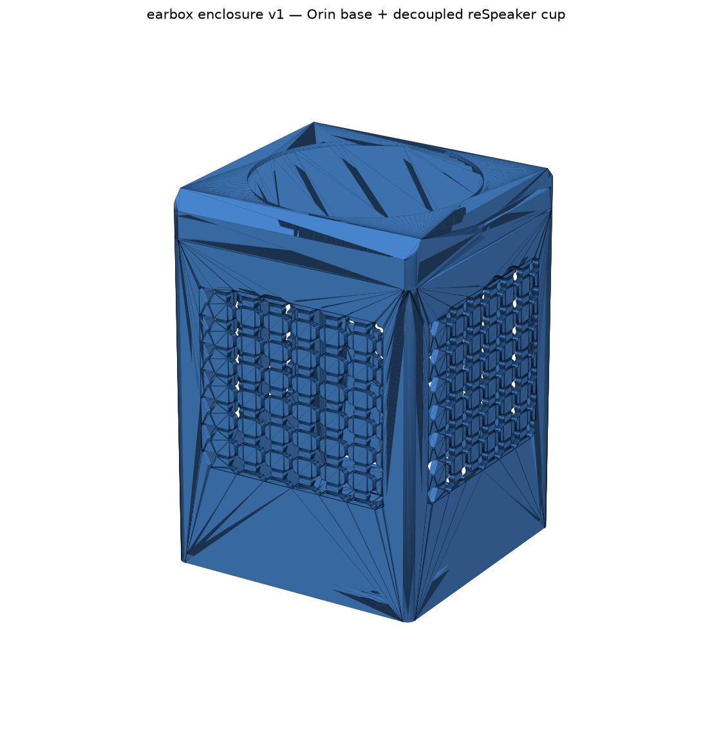
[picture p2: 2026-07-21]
hardware/enclosure/preview_v2.png

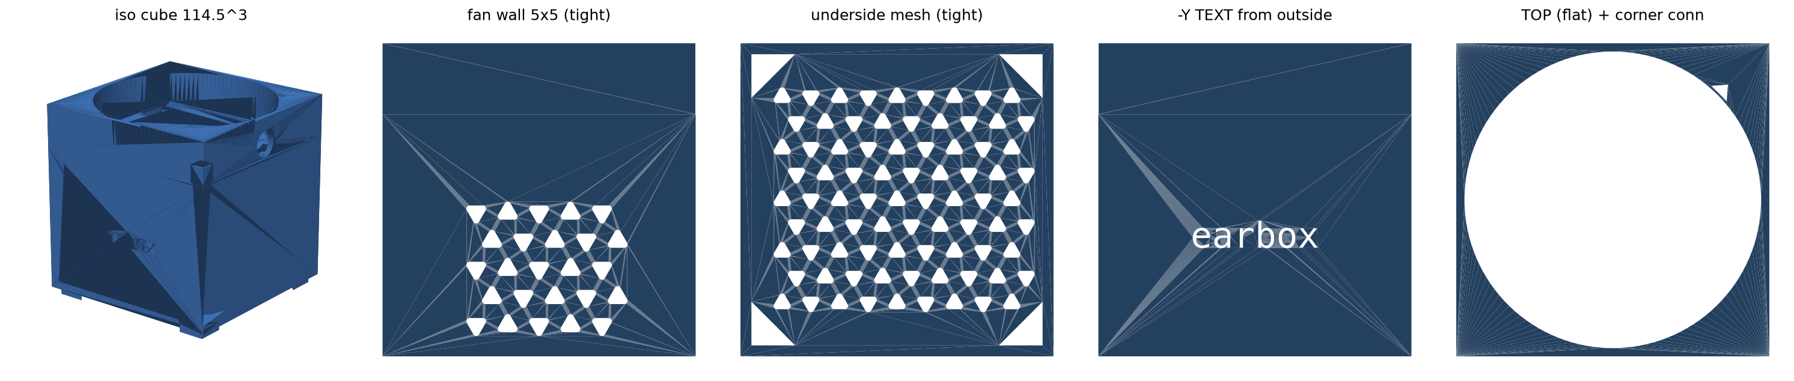
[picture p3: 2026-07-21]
hardware/enclosure/preview_v4.png

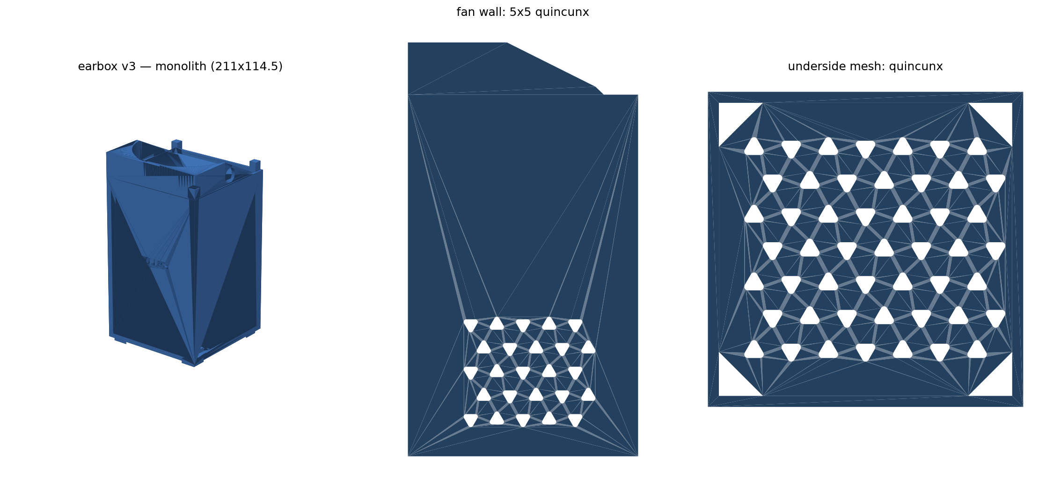
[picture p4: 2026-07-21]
hardware/enclosure/preview_v3.png

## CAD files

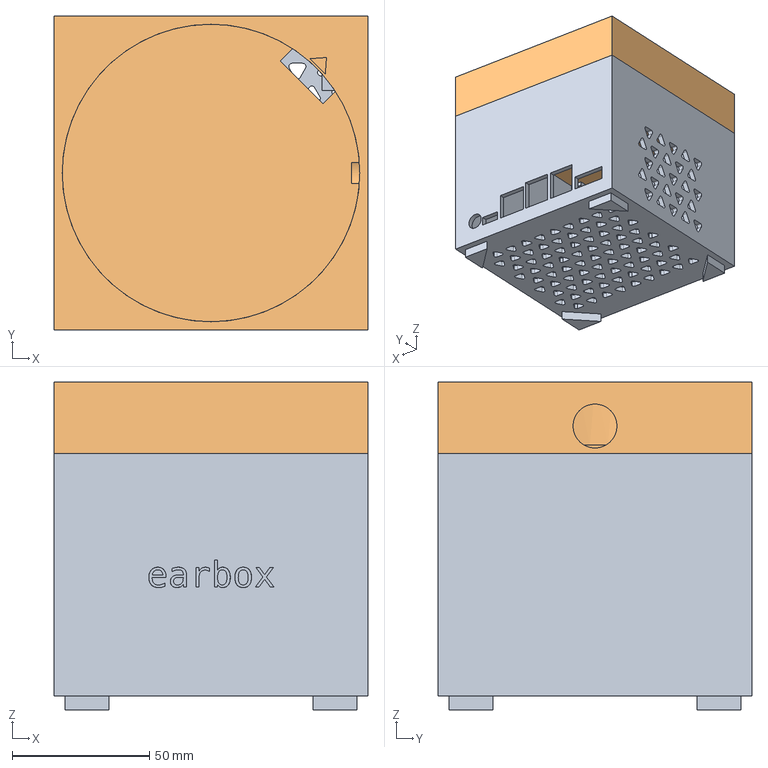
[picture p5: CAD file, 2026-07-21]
hardware/enclosure/earbox_v4.step
114.5 x 114.5 x 119.5 mm
mono_base
mono_crown

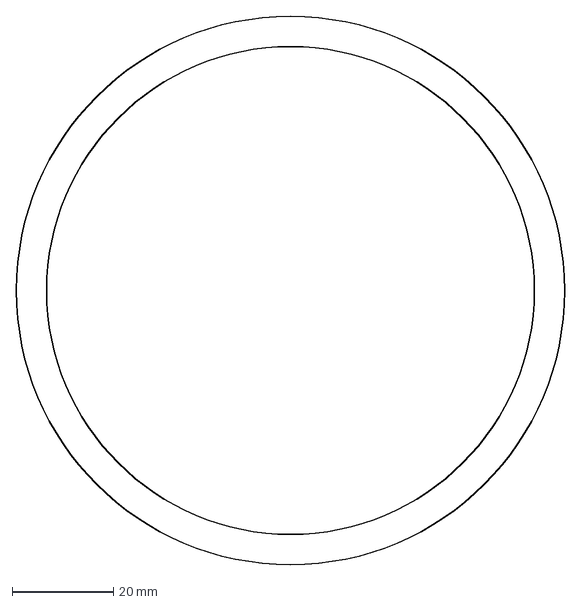
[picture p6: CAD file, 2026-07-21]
hardware/enclosure/foam_gasket.dxf
108.5 x 108.5 mm

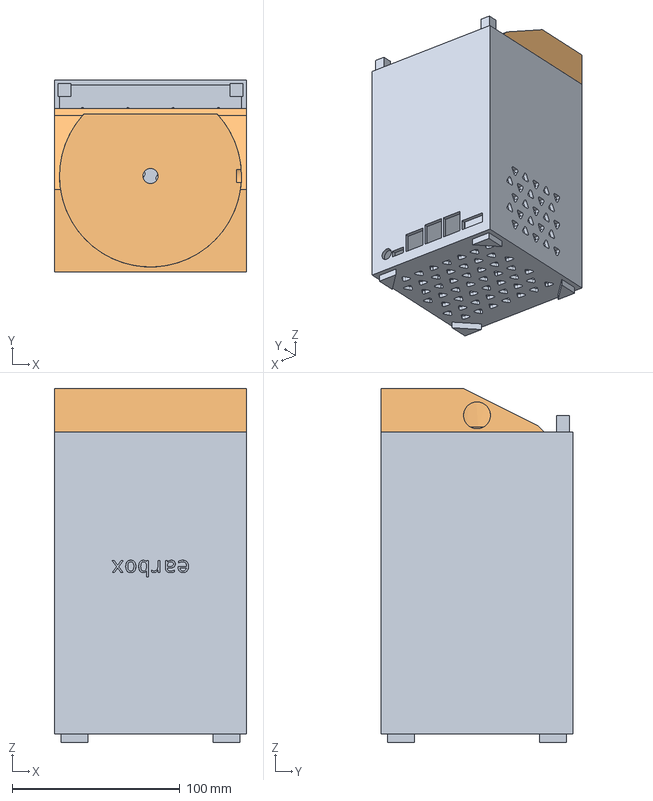
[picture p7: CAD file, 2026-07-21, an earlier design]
hardware/enclosure/earbox_v3.step
114.5 x 114.5 x 211.0 mm
mono_base
mono_crown

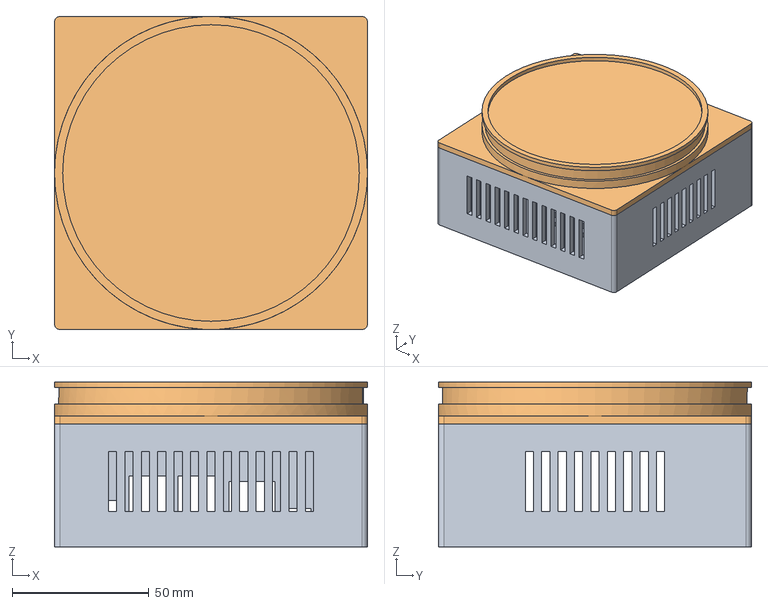
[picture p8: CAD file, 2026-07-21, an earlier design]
hardware/enclosure/earbox_v1.step
114.5 x 114.5 x 60.4 mm
orin_base
mic_tower

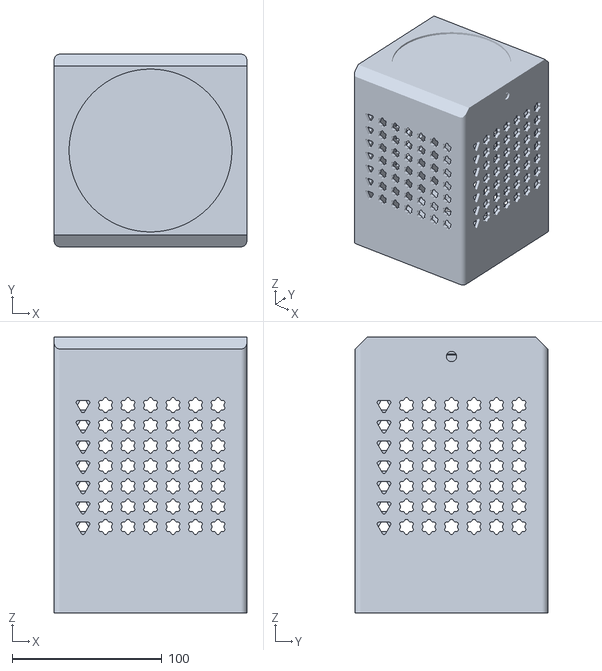
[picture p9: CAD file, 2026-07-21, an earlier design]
hardware/enclosure/earbox_v2.stl
128.5 x 128.5 x 184.0

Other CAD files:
hardware/enclosure/earbox_v1.stl
hardware/enclosure/earbox_v3.stl
hardware/enclosure/earbox_v4.stl

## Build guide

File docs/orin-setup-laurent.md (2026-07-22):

# Installation Orin Nano Super — guide pas à pas pour Laurent

Objectif: allumer l'Orin, le connecter à internet, et me donner (Tony) un accès à
distance en SSH via ton VPN WireGuard (celui qui tourne déjà sur ton droplet à
Singapour). Aucune compétence de développeur requise: chaque étape = une action +
comment vérifier qu'elle a marché.

Temps réel à prévoir: environ 2 à 3 heures. Si tout se passe bien, 1 h 15. La
plus grosse partie, c'est le téléchargement et la copie de l'image sur la carte
microSD (fichier de ~9 Go).

Choix technique important (pour cette phase, au plus simple et fiable):
- Le système Ubuntu ET les données (modèles, transcriptions) tournent depuis la
  carte microSD de 128 Go. Il reste ~95 Go de libre, largement assez pour ce
  sprint.
- Il n'y a PAS de SSD NVMe monté sur /data pour cette phase: le NVMe a été retiré
  et mis de côté (restauration garantie plus tard, sans perte de données). On
  pourra rebrancher un NVMe et déplacer les données dessus quand on voudra —
  c'est optionnel.

Matériel nécessaire:
- L'Orin Nano Super et son alimentation.
- La carte microSD (128 Go).
- (Le SSD NVMe n'est PAS nécessaire pour cette phase — il a été retiré et mis de
  côté; on le restaurera plus tard, sans perte.)
- Un écran + un câble DisplayPort. ATTENTION: l'Orin n'a PAS de prise HDMI, il a
  une prise DisplayPort. Si ton écran n'a que du HDMI, il te faut un câble
  "DisplayPort vers HDMI" (quelques euros).
- Un clavier et une souris USB.
- Ton ordinateur (Windows ou Mac) pour préparer la carte microSD.
- Le micro reSpeaker XVF3800 (on le branche plus tard, pas tout de suite).

---

## Étape 1 — Monter le SSD, préparer la carte microSD, et démarrer

### 1a. Installer le SSD NVMe — À SAUTER pour ce sprint

Pour cette phase on tourne UNIQUEMENT sur la carte microSD. Le SSD NVMe a été
retiré et mis de côté (restauration garantie plus tard, sans perte). Tu peux donc
SAUTER les points 1 à 4 ci-dessous et passer directement à la partie 1b.

Les points 1 à 4 ne servent QUE si tu réinstalles un jour le SSD (optionnel):

1. Débranche complètement l'Orin (pas d'alimentation branchée).
2. Retourne la carte de l'Orin: le slot pour le SSD est SOUS la carte. C'est le
   long connecteur "M.2 Key M" (le seul assez long pour un SSD).
3. Retire la petite vis qui est en face du slot (garde-la, tu en as besoin).
4. Glisse le SSD dans le slot, en biais (environ 30°), jusqu'à ce qu'il soit bien
   enfoncé. Puis rabats-le à plat et revisse la petite vis pour le maintenir.

### 1b. Copier le système sur la carte microSD (sur TON ordinateur)

5. Sur ton ordinateur, télécharge l'image JetPack 6.2 pour "Jetson Orin Nano
   Developer Kit" ici:

```
https://developer.nvidia.com/embedded/jetpack-sdk-62
```

Cherche le lien "SD Card Image" pour l'Orin Nano Developer Kit. C'est un gros
fichier .zip (~9 Go). Ne le décompresse pas.

6. Télécharge le logiciel Balena Etcher (gratuit) et installe-le:

```
https://etcher.balena.io
```

7. Mets la carte microSD dans ton ordinateur (avec un lecteur de carte si
   besoin). Ouvre Balena Etcher:
   - "Flash from file" -> choisis le fichier .zip téléchargé.
   - "Select target" -> choisis la carte microSD (bien vérifier que c'est la
     carte et pas un autre disque).
   - Clique "Flash". Ça prend 15 à 30 minutes.

Vérification: Etcher affiche "Flash Complete!" en vert. Retire la carte
proprement (éjecter), puis insère-la dans l'Orin (le slot microSD est sur le
module, à côté du ventilateur).

### 1c. Premier démarrage

8. Branche l'écran (DisplayPort), le clavier et la souris USB, puis
   l'alimentation. L'Orin démarre tout seul.

Vérification: après 1 à 2 minutes, l'écran affiche le logo NVIDIA puis l'écran
d'installation d'Ubuntu.

IMPORTANT — si l'écran reste NOIR après plusieurs minutes: c'est très
probablement que le "firmware" d'usine de l'Orin est trop ancien pour JetPack
6.2. C'est la seule manip que je préfère faire avec toi en direct (appelle-moi /
écris-moi), on ne se lance pas là-dedans à l'aveugle. Beaucoup de kits "Super"
récents démarrent directement, donc il y a de bonnes chances que ça marche du
premier coup.

---

## Étape 2 — Configurer Ubuntu (assistant au premier démarrage)

9. Suis l'assistant à l'écran: langue, fuseau horaire, clavier.
10. Quand il demande de créer un utilisateur, mets EXACTEMENT:
    - Nom / nom d'utilisateur: earbox
    - Mot de passe: celui que tu veux (note-le bien, on en aura besoin).
11. Choisis le réseau: Wi-Fi (entre le mot de passe de ta box) ou câble Ethernet
    (encore plus simple et stable si tu peux).

Vérification: l'Orin arrive sur le bureau Ubuntu. Ouvre le navigateur et va sur
un site web quelconque: si la page s'affiche, internet fonctionne.

Ouvre maintenant l'application "Terminal" (icône avec un carré noir, ou cherche
"Terminal" dans les applications). Toutes les commandes suivantes se tapent dans
ce Terminal, une par une. Astuce: pour coller dans le Terminal, utilise
Ctrl+Maj+V.

---

## Étape 3 — Activer et vérifier le SSH

Le SSH est ce qui me permettra de me connecter à distance. Il est normalement
déjà actif sur JetPack, on le vérifie.

12. Active le SSH (sans risque même s'il est déjà actif):

```
sudo systemctl enable --now ssh
```

13. Vérifie qu'il tourne:

```
systemctl status ssh
```

Vérification: tu dois voir le mot "active (running)" en vert. Appuie sur "q" pour
sortir de l'affichage.

---

## Étape 4 — Raccorder l'Orin à ton VPN WireGuard

On réutilise le VPN WireGuard que tu as déjà monté sur ton droplet à Singapour
(le même où le "rig" est déjà connecté). On ajoute juste l'Orin comme nouveau
membre du VPN.

14. Installe WireGuard sur l'Orin:

```
sudo apt update && sudo apt install -y wireguard
```

Vérification: ça se termine sans erreur. Tu peux contrôler avec:

```
wg --version
```

15. Génère la paire de clés de l'Orin (sa clé privée + sa clé publique):

```
wg genkey | sudo tee /etc/wireguard/orin_private.key | wg pubkey | sudo tee /etc/wireguard/orin_public.key
```

Vérification: affiche la clé publique de l'Orin (tu en auras besoin sur le
droplet):

```
sudo cat /etc/wireguard/orin_public.key
```

Note aussi la clé privée (tu en as besoin à l'étape 17):

```
sudo cat /etc/wireguard/orin_private.key
```

16. Sur ton droplet à Singapour, ajoute l'Orin comme nouveau peer, exactement
    comme tu l'as fait pour le rig: une entrée [Peer] avec la clé publique de
    l'Orin (celle de l'étape 15) et une adresse VPN libre que tu lui attribues
    (par exemple 10.0.0.4/32 — à toi de choisir une IP non utilisée dans ton
    sous-réseau VPN). Recharge la config du serveur comme d'habitude.

    Profites-en pour créer AUSSI un peer pour MOI (Tony): une nouvelle paire de
    clés + une IP VPN libre (par exemple 10.0.0.5). Colle-moi ma config complète
    (fichier .conf) dans le groupe, je m'en sers pour rejoindre le VPN de mon
    côté.

Vérification: côté droplet, ton `wg show` liste maintenant le peer de l'Orin.

17. Sur l'Orin, crée le fichier de config du tunnel:

```
sudo nano /etc/wireguard/wg0.conf
```

Colle ce modèle en remplaçant les 4 valeurs entre <...> (mêmes réglages que pour
le rig): l'adresse VPN que tu as donnée à l'Orin, sa clé privée (étape 15), la
clé publique de ton droplet, et l'adresse publique du droplet:

```
[Interface]
Address = <IP_VPN_DE_L_ORIN>/24
PrivateKey = <CLE_PRIVEE_DE_L_ORIN>

[Peer]
PublicKey = <CLE_PUBLIQUE_DU_DROPLET>
Endpoint = <IP_PUBLIQUE_DU_DROPLET>:51820
AllowedIPs = 10.0.0.0/24
PersistentKeepalive = 25
```

Enregistre: Ctrl+O, Entrée, puis Ctrl+X. (Si ton sous-réseau VPN n'est pas
10.0.0.0/24, mets le tien, le même que pour le rig.)

18. Active le tunnel et fais-le démarrer automatiquement:

```
sudo systemctl enable --now wg-quick@wg0
```

19. Vérifie que le tunnel est monté:

```
sudo wg show
```

Vérification: tu vois le peer du droplet avec une ligne "latest handshake" (une
poignée de main récente = ça communique).

20. Teste en pingant le droplet à travers le tunnel (remplace par l'IP VPN de ton
    droplet, souvent 10.0.0.1):

```
ping -c 3 10.0.0.1
```

Vérification: tu reçois des réponses ("3 received"). Note l'adresse VPN que tu as
donnée à l'Orin (étape 16), tu me l'enverras: c'est celle que j'utiliserai pour
me connecter en SSH.

---

## Étape 5 — Me donner l'accès SSH (Tony)

Une fois que je serai sur le VPN (avec la config que tu m'as collée à l'étape 16),
je pourrai joindre l'Orin par son IP VPN. Il reste à mettre ma clé SSH pour
l'authentification.

### 5B. Ajouter ma clé SSH

Je vais t'envoyer une ligne de texte (ma "clé publique"). Elle ressemble à ça et
COMMENCE par ssh-ed25519 (c'est un exemple, utilise celle que je t'envoie):

```
ssh-ed25519 AAAAC3NzaC1lZDI1... tony@earbox
```

21. Prépare le dossier:

```
mkdir -p ~/.ssh && chmod 700 ~/.ssh
```

22. Ouvre le fichier des clés autorisées avec l'éditeur nano:

```
nano ~/.ssh/authorized_keys
```

Colle la ligne que je t'ai envoyée (Ctrl+Maj+V), sur une seule ligne. Puis
enregistre: Ctrl+O, Entrée, puis Ctrl+X pour quitter.

23. Sécurise le fichier:

```
chmod 600 ~/.ssh/authorized_keys
```

Vérification: affiche le contenu, tu dois voir ma clé:

```
cat ~/.ssh/authorized_keys
```

24. Envoie-moi: l'adresse VPN de l'Orin (étape 16) + confirme que tu as collé ma
    clé. Je teste la connexion et je te dis si c'est bon.

---

## Étape 6 — Brancher le micro reSpeaker XVF3800

25. Branche le micro reSpeaker sur un port USB de l'Orin. Aucun pilote à
    installer, c'est reconnu tout seul.

26. Liste les cartes son / micros détectés:

```
arecord -l
```

Vérification: tu dois voir une ligne mentionnant le reSpeaker (ou "XVF3800" /
"USB Audio"). Fais une capture d'écran (ou recopie le texte) et envoie-la-moi:
j'en ai besoin pour la config audio.

---

## Étape 7 — Stockage (rien à faire)

Pour ce sprint, l'Orin tourne UNIQUEMENT sur la carte microSD de 128 Go (~95 Go
libres, largement assez pour le système, les modèles et les transcriptions). Il
n'y a PAS de SSD NVMe à formater ni à monter sur /data: le NVMe a été retiré et
mis de côté (restauration garantie plus tard, sans perte de données). Un NVMe
reste optionnel et pourra être ajouté ensuite. Tu peux passer directement à la
suite.

---

## Mettre à jour la box (sans sudo)

Une fois installée, la box tourne depuis le clone git de l'utilisateur `earbox`
(`~/earbox`), pas depuis une copie root. Donc les mises à jour de code ne
demandent AUCUN mot de passe root. Dans le Terminal, en tant qu'`earbox`:

```
cd ~/earbox && git pull && earbox-restart
```

`earbox-restart` arrête juste le service; il redémarre tout seul sur le nouveau
code en quelques secondes (le service a `Restart=always`). Pas de `sudo`, pas de
`systemctl restart`. (C'est surtout moi, Tony, qui ferai ça à distance.)

---

## C'est fini

Une fois l'étape 5 confirmée (je réussis à me connecter) et l'étape 6 envoyée
(sortie de arecord -l), je prends le relais à distance pour installer le reste.

Récapitulatif de ce que tu dois m'envoyer:
- Ma config WireGuard (le fichier .conf que tu génères pour moi, étape 16).
- L'adresse VPN de l'Orin (étape 16).
- Confirmation que ma clé SSH est collée (étape 23).
- La capture de "arecord -l" (étape 26).

Merci Laurent, et n'hésite pas à m'écrire au moindre blocage, surtout si l'écran
reste noir au premier démarrage.

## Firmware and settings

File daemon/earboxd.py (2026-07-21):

#!/usr/bin/env python3
"""
earboxd - the earbox capture -> transcribe -> memory daemon.

Privacy invariants enforced here (see docs/architecture.md):
  1. Raw audio is written only to a tmpfs scratch path and DELETED immediately
     after transcription. It is never persisted to disk-at-rest, never sent
     off-device.
  2. Only text (transcripts) is written to the owner's git-backed memory.
  3. A physical mute switch (GPIO on the Pi) or a mute flag file gates capture:
     when muted, no audio is captured at all.
  4. Nothing leaves the device from this process. Egress (daily summary to the
     owner's agent) is a separate, text-only step (summarize.py).

The daemon is source-agnostic. On the Pi the source is `arecord`; on a Mac dev
box it is `ffmpeg`/avfoundation; in tests it is a wav file replayed as chunks.
"""

import argparse
import array
import datetime as dt
import math
import os
import re
import shutil
import subprocess
import sys
try:
    import tomllib
except ModuleNotFoundError:
    import tomli as tomllib
import wave
from pathlib import Path

# ---- config -----------------------------------------------------------------

DEFAULTS = {
    "segment_seconds": 30,
    "sample_rate": 16000,
    "model_path": os.path.expanduser("~/.whisper-models/ggml-base.bin"),
    "language": "fr",
    "whisper_bin": "whisper-cli",
    "whisper_threads": 4,
    "memory_repo": os.path.expanduser("~/earbox-memory"),
    "scratch_dir": "/dev/shm/earbox",          # tmpfs on Linux -> never hits disk
    "vad_rms_threshold": 0.012,                 # 0..1, skip chunks quieter than this
    "vad_min_voiced_ratio": 0.06,               # >=6% of frames must be "loud"
    "mute_flag": os.path.expanduser("~/.earbox-muted"),
    "gpio_mute_pin": 0,                          # 0 = disabled; else BCM pin number
    "auto_commit": True,
    "keep_debug_audio": False,                   # MUST stay false in production
}

# whisper on silence/noise hallucinates these; drop them.
HALLUCINATIONS = {
    "", "[blank_audio]", "[ silence ]", "[silence]", "(silence)",
    "merci", "merci.", "sous-titres réalisés par la communauté d'amara.org",
    "sous-titrage société radio-canada", "thank you.", "thanks for watching!",
    "you", "so", ".", "...", "[music]", "(applause)", "[applause]", "♪",
}


def load_config(path):
    cfg = dict(DEFAULTS)
    if path and Path(path).exists():
        with open(path, "rb") as f:
            cfg.update(tomllib.load(f))
    return cfg


# ---- mute -------------------------------------------------------------------

def is_muted(cfg):
    if Path(cfg["mute_flag"]).exists():
        return True
    pin = int(cfg.get("gpio_mute_pin") or 0)
    if pin:
        try:
            import gpiozero  # only present on the Pi
            btn = _gpio_button(pin)
            return btn.is_pressed  # switch closed == muted
        except Exception:
            return False
    return False


_GPIO_CACHE = {}
def _gpio_button(pin):
    if pin not in _GPIO_CACHE:
        from gpiozero import Button
        _GPIO_CACHE[pin] = Button(pin, pull_up=True)
    return _GPIO_CACHE[pin]


# ---- capture ----------------------------------------------------------------

def capture_arecord(cfg, out_path):
    subprocess.run(
        ["arecord", "-q", "-D", cfg.get("alsa_device", "default"),
         "-f", "S16_LE", "-r", str(cfg["sample_rate"]), "-c", "1",
         "-d", str(cfg["segment_seconds"]), str(out_path)],
        check=True,
    )


def capture_ffmpeg(cfg, out_path):
    # macOS dev harness: :0 is the default avfoundation audio input.
    subprocess.run(
        ["ffmpeg", "-y", "-loglevel", "error", "-f", "avfoundation",
         "-i", cfg.get("av_device", ":0"), "-t", str(cfg["segment_seconds"]),
         "-ar", str(cfg["sample_rate"]), "-ac", "1", "-c:a", "pcm_s16le",
         str(out_path)],
        check=True,
    )


# ---- VAD (energy based, dependency-free) ------------------------------------

def rms_voiced_ratio(wav_path, frame_ms=30):
    """Return (overall_rms_0_1, voiced_frame_ratio). Pure stdlib."""
    with wave.open(str(wav_path), "rb") as w:
        assert w.getsampwidth() == 2, "expect 16-bit PCM"
        rate = w.getframerate()
        raw = w.readframes(w.getnframes())
    if not raw:
        return 0.0, 0.0
    samples = array.array("h")
    samples.frombytes(raw)
    n = len(samples)
    if n == 0:
        return 0.0, 0.0
    total_sq = sum(s * s for s in samples)
    overall = math.sqrt(total_sq / n) / 32768.0
    fs = max(1, int(rate * frame_ms / 1000))
    loud = 0
    frames = 0
    thr = 0.02  # per-frame loudness gate
    for i in range(0, n - fs, fs):
        frames += 1
        seg = samples[i:i + fs]
        fr = math.sqrt(sum(s * s for s in seg) / len(seg)) / 32768.0
        if fr > thr:
            loud += 1
    ratio = loud / frames if frames else 0.0
    return overall, ratio


def has_speech(cfg, wav_path):
    overall, ratio = rms_voiced_ratio(wav_path)
    return overall >= cfg["vad_rms_threshold"] and ratio >= cfg["vad_min_voiced_ratio"]


# ---- transcription ----------------------------------------------------------

def transcribe(cfg, wav_path):
    proc = subprocess.run(
        [cfg["whisper_bin"], "-m", cfg["model_path"], "-l", cfg["language"],
         "-t", str(cfg["whisper_threads"]), "-nt", "-f", str(wav_path)],
        capture_output=True, text=True, check=True,
    )
    return clean_transcript(proc.stdout)


def clean_transcript(text):
    lines = [ln.strip() for ln in text.splitlines()]
    out = []
    for ln in lines:
        norm = ln.lower().strip()
        norm = re.sub(r"\s+", " ", norm)
        if norm in HALLUCINATIONS:
            continue
        # drop pure bracket/paren tags like [_BEG_], (wind blowing)
        if re.fullmatch(r"[\[\(].*[\]\)]", norm):
            continue
        if ln:
            out.append(ln)
    joined = " ".join(out).strip()
    # collapse whisper's degenerate repetition loops
    joined = re.sub(r"(\b\w+\b)( \1){3,}", r"\1", joined)
    return joined


# ---- memory (git-backed) ----------------------------------------------------

def ensure_repo(cfg):
    repo = Path(cfg["memory_repo"])
    repo.mkdir(parents=True, exist_ok=True)
    if not (repo / ".git").exists():
        subprocess.run(["git", "init", "-q"], cwd=repo, check=True)
        _git_identity(repo)
        gi = repo / ".gitignore"
        gi.write_text("*.wav\n*.aiff\n*.raw\n*.pcm\n")  # never commit audio
        (repo / "README.md").write_text(
            "# earbox memory\n\nText transcripts only. No audio ever lives here.\n")
        subprocess.run(["git", "add", "-A"], cwd=repo, check=True)
        subprocess.run(["git", "commit", "-q", "-m", "init earbox memory"],
                       cwd=repo, check=True)
    return repo


def _git_identity(repo):
    subprocess.run(["git", "config", "user.name", "earbox"], cwd=repo, check=True)
    subprocess.run(["git", "config", "user.email", "earbox@localhost"],
                   cwd=repo, check=True)


def append_transcript(cfg, repo, text, when=None):
    when = when or dt.datetime.now()
    day = when.strftime("%Y-%m-%d")
    daydir = repo / "transcripts"
    daydir.mkdir(exist_ok=True)
    md = daydir / f"{day}.md"
    if not md.exists():
        md.write_text(f"# {day}\n\n")
    with open(md, "a") as f:
        f.write(f"- **{when.strftime('%H:%M')}** {text}\n")
    if cfg["auto_commit"]:
        subprocess.run(["git", "add", str(md)], cwd=repo, check=True)
        subprocess.run(
            ["git", "commit", "-q", "-m", f"transcript {when.strftime('%Y-%m-%d %H:%M')}"],
            cwd=repo, check=True,
        )
    return md


# ---- main loop --------------------------------------------------------------

def process_segment(cfg, repo, wav_path, when=None):
    """VAD -> transcribe -> memory -> DELETE. Returns transcript text or None."""
    text = None
    try:
        if not has_speech(cfg, wav_path):
            return None
        text = transcribe(cfg, wav_path)
        if not text:
            return None
        append_transcript(cfg, repo, text, when)
        return text
    finally:
        # PRIVACY INVARIANT: raw audio is destroyed no matter what.
        if not cfg["keep_debug_audio"]:
            try:
                os.remove(wav_path)
            except FileNotFoundError:
                pass


def run(cfg, source):
    repo = ensure_repo(cfg)
    scratch = Path(cfg["scratch_dir"])
    scratch.mkdir(parents=True, exist_ok=True)
    capture = capture_arecord if source == "arecord" else capture_ffmpeg
    seg = 0
    print(f"[earboxd] listening: model={Path(cfg['model_path']).name} "
          f"lang={cfg['language']} seg={cfg['segment_seconds']}s "
          f"source={source} memory={cfg['memory_repo']}", flush=True)
    while True:
        if is_muted(cfg):
            _sleep(1)
            continue
        wav = scratch / f"seg_{seg:06d}.wav"
        try:
            capture(cfg, wav)
        except subprocess.CalledProcessError as e:
            print(f"[earboxd] capture failed: {e}", file=sys.stderr, flush=True)
            _sleep(2)
            continue
        text = process_segment(cfg, repo, wav)
        if text:
            print(f"[earboxd] +{len(text)} chars committed", flush=True)
        seg += 1


def _sleep(s):
    import time
    time.sleep(s)


def main(argv=None):
    p = argparse.ArgumentParser(description="earbox capture->transcribe->memory daemon")
    p.add_argument("--config", default=os.path.expanduser("~/.config/earbox/config.toml"))
    p.add_argument("--source", choices=["arecord", "ffmpeg"], default=None,
                   help="capture source (default: arecord on Linux, ffmpeg on macOS)")
    args = p.parse_args(argv)
    cfg = load_config(args.config)
    source = args.source or ("arecord" if sys.platform.startswith("linux") else "ffmpeg")
    run(cfg, source)


if __name__ == "__main__":
    main()

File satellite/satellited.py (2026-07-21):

#!/usr/bin/env python3
"""
satellited - the earbox MIC SATELLITE daemon (Raspberry Pi 4).

OPTIONAL multi-room tier. The founder unit does NOT need this (the Orin captures
its local XVF3800 directly). A satellite is a cheap Pi 4 + mic in another room
that streams that room's speech to the Orin brain over the LAN.

Pipeline (ZERO storage on the Pi):
  arecord (mic) -> tmpfs wav -> energy VAD gate -> encode (opus/pcm)
    -> stream over TLS to the Orin -> DELETE the tmpfs wav immediately.

The Pi keeps no transcripts and no audio: it is a dumb, encrypted microphone.
All transcription, memory and deletion-of-record happen on the Orin. If the
mute flag/GPIO is set, the mic is never opened.

Discovery: set `orin_host` statically, or leave it empty to mDNS-discover the
Orin advertising _earbox._tcp (needs python zeroconf on the Pi).
"""

import argparse
import os
import sys
from pathlib import Path

sys.path.insert(0, str(Path(__file__).resolve().parent.parent))  # repo root on path

from common import earbox_core as core       # noqa: E402
from common import wire                       # noqa: E402
from common import codec as codeclib          # noqa: E402

SAT_DEFAULTS = dict(core.DEFAULTS)
SAT_DEFAULTS.update({
    "satellite_id": "satellite",
    "orin_host": "",                 # empty -> mDNS discover
    "orin_port": 7217,
    "codec": "opus",                 # opus (opus-tools) or pcm
    "tls_cafile": "/opt/earbox/tls/orin.crt",   # pinned Orin cert
    "alsa_device": "default",
    "memory_repo": "",               # satellites have NO memory
})


def discover_orin(cfg, timeout=8):
    host = cfg.get("orin_host") or ""
    if host:
        return host, int(cfg["orin_port"])
    from zeroconf import Zeroconf, ServiceBrowser
    import time
    found = {}

    class _L:
        def add_service(self, zc, type_, name):
            info = zc.get_service_info(type_, name)
            if info and info.addresses:
                import socket as _s
                found["host"] = _s.inet_ntoa(info.addresses[0])
                found["port"] = info.port

        def update_service(self, *a):
            pass

        def remove_service(self, *a):
            pass

    zc = Zeroconf()
    ServiceBrowser(zc, "_earbox._tcp.local.", _L())
    deadline = time.time() + timeout
    while time.time() < deadline and "host" not in found:
        time.sleep(0.2)
    zc.close()
    if "host" not in found:
        raise RuntimeError("no Orin found via mDNS; set orin_host in config")
    return found["host"], found["port"]


def capture_segment(cfg, out_wav_path):
    import subprocess
    subprocess.run(
        ["arecord", "-q", "-D", cfg.get("alsa_device", "default"),
         "-f", "S16_LE", "-r", str(cfg["sample_rate"]), "-c", "1",
         "-d", str(cfg["segment_seconds"]), str(out_wav_path)],
        check=True,
    )
    return out_wav_path


def run(cfg, grab=None):
    grab = grab or capture_segment
    host, port = discover_orin(cfg)
    ctx = wire.client_tls_context(cfg["tls_cafile"])
    scratch = Path(cfg["scratch_dir"]); scratch.mkdir(parents=True, exist_ok=True)
    codec = cfg["codec"]
    core.log("satellite", f"'{cfg['satellite_id']}' -> orin {host}:{port} "
                          f"(codec={codec}, TLS)")
    conn = wire.connect(host, int(port), ctx)
    wire.send_header(conn, cfg["satellite_id"], codec,
                     cfg["sample_rate"], cfg["segment_seconds"])
    seg = 0
    try:
        while True:
            if core.is_muted(cfg):
                core.sleep(1); continue
            wav = scratch / f"sat_{seg:06d}.wav"
            try:
                grab(cfg, wav)
                if core.has_speech(cfg, wav):
                    payload = codeclib.encode(codec, wav)
                    wire.send_frame(conn, payload)
                    core.log("satellite", f"seg {seg}: sent {len(payload)} bytes")
            finally:
                # ZERO STORAGE: the raw wav is destroyed on the Pi immediately,
                # whether or not it was voiced or sent.
                if wav.exists():
                    try:
                        os.remove(wav)
                    except FileNotFoundError:
                        pass
            seg += 1
    finally:
        try:
            conn.unwrap()  # clean TLS close so the Orin sees EOF, not a reset
        except OSError:
            pass
        conn.close()


def main(argv=None):
    p = argparse.ArgumentParser(description="earbox Pi mic satellite")
    p.add_argument("--config", default=os.path.expanduser("~/.config/earbox/satellite.toml"))
    args = p.parse_args(argv)
    cfg = core.load_config(args.config, defaults=SAT_DEFAULTS)
    run(cfg)


if __name__ == "__main__":
    main()

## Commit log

2026-07-21 refactor: extract shared earbox_core + wire/codec into common/
    Move the privacy-critical D1 logic (energy VAD, transcript cleaning, git
    memory, mute, delete-in-finally process_segment) into common/earbox_core.py
    as the single source of truth both tiers import, so it can't drift. Add
    wire.py (LAN hop: JSON header + length-prefixed frames over TLS) and codec.py
    (per-segment pcm/opus encode-decode).
    [codec.py, earbox_core.py, wire.py]
2026-07-21 feat(orin): Jetson Orin brain daemon (direct XVF3800 + optional LAN server)
    orind.py runs two input modes into one pipeline (VAD -> optional denoise ->
    STT -> git memory -> delete-in-finally):
    - direct (PRIMARY founder unit): capture the local reSpeaker XVF3800 USB mic
    on the Orin, no network. capture.py feeds whisper the DSP-processed ASR
    channel (channel layout configurable, must be confirmed on-device).
    - lan (OPTIONAL multi-room): TLS server receiving encrypted segments from Pi
    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
2026-07-21 feat(satellite): optional Pi 4 mic satellite (capture->VAD->opus->TLS, zero storage)
    satellited.py streams a remote room to the Orin over the encrypted LAN hop:
    arecord -> energy VAD gate -> opus/pcm encode -> TLS frame -> delete the tmpfs
    wav immediately. The Pi keeps zero storage: no transcripts, no memory, just an
    encrypted microphone. Static orin_host or mDNS discovery; pins the Orin's
    self-signed cert. provision.sh (Pi OS Lite), systemd unit, config.example.toml.
2026-07-21 test: Mac two-tier harness proves the full plumbing end-to-end
    harness_twotier.py spawns the REAL orind.py in lan mode with real self-signed
    TLS, then streams a wav through a loopback satellite over the real TLS socket
    using the exact wire framing + codec the Pi uses. The Orin decodes each
    segment in tmpfs -> whisper_cli STT -> git commit -> delete. Verified locally:
    single + multi-segment French transcription committed, 0 stray audio,
    TWO-TIER PLUMBING: WORKED. Only faster-whisper itself is untested (needs the
    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
2026-07-21 docs: lock two-tier architecture (Orin+XVF3800 single-box primary, Pi satellite optional)
    Rewrite architecture.md + README to the locked design: founder unit = Jetson
    Orin Nano Super + reSpeaker XVF3800 USB mic in one box (no LAN hop);
    faster-whisper CUDA int8 STT; software denoise default-OFF (XVF3800 does DSP
    on-chip); Pi satellite demoted to optional multi-room. Honest notes: all
    Orin/XVF3800 code is UNTESTED-ON-TARGET; small/medium int8 RTF must be
    benchmarked on-device in real kitchen noise (D3); Hailo excluded for STT
    (vision silicon, no Whisper path); self-signed TLS hop needs WireGuard/mutual
    -TLS hardening; a private git remote is still needed for the team. Update the
    7-day plan (D3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
2026-07-21 docs: add Orin Nano Super setup guide for Laurent (WireGuard remote access)
2026-07-21 chore(orin): run SD-only for the sprint, make NVMe /data optional
    The Orin now runs from the 128GB microSD only; there is no /data NVMe
    mount for the sprint. provision.sh resolves a STORAGE_ROOT that defaults
    to the service user's home on the SD and uses /data only if it is
    actually mounted (EARBOX_DATA overrides). Memory repo, models dir, and
    the systemd ReadWritePaths all derive from it, so the SD default is
    byte-identical to the old hardcoded paths and a later NVMe is a
    one-variable move. Drop the NVMe parted/mount step from Laurent's guide
    (replaced with an SD-only note + NVMe-shelved restoration guarantee) and
    update the architecture storage notes.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
2026-07-21 docs: record love-first LED easter egg and audio-never-on-disk roadmap
2026-07-21 feat(enclosure): parametric build123d source for founder-unit v1
    Two-chamber tower: vented Jetson Orin Nano Super base + acoustically
    decoupled reSpeaker XVF3800 cup (stock case kept for v1). Foam-gasket
    DXF generator, preview renderer, and README with VERIFIED/UNVERIFIED
    dims and foam spec for Laurent. STEP/STL/PNG binaries to follow once the
    OCP toolchain finishes installing on this box.
2026-07-21 feat(enclosure): generate STEP/STL/DXF + preview for v1
    build123d 0.11.1 export: two-part assembly (orin_base + mic_tower),
    111x110x62 mm, each a single watertight solid. Foam gasket DXF and an
    isometric preview PNG. Fixes DXF export to the ExportDXF class API.
    [earbox_v1.step, earbox_v1.stl, foam_gasket.dxf]
2026-07-21 feat(enclosure): v2 vertical monolith — printable, verified case dims
    Laurent's v2 language: vertical monolith, two-edge truncated crown,
    rounded-triangle mesh venting. reSpeaker case now VERIFIED 107x17 (caliper);
    0.75mm FDM clearance on all fits; easy-open two-part split (base spigot +
    crown groove, pry-off, nothing captive). Both parts single watertight solids.
    [earbox_v2.stl]
2026-07-21 docs(enclosure): v2 README section, preview, regenerated v1 artifacts
    Documents the monolith design language, verified 107x17 case dims, 0.75mm
    fits, the easy-open spigot/groove split, print orientation, and the three
    design-vs-constraint conflicts + resolutions. Adds preview_v2.png; regenerates
    v1 STEP/STL/DXF/preview against the verified dims.
    [earbox_v1.step, earbox_v1.stl, foam_gasket.dxf]
2026-07-21 feat(enclosure): v3 vertical monolith to Laurent's literal spec
    Rectangular tall/narrow box (211x114.5, height largest), 3mm shell, diagonal
    two-facet truncated summit, 4 triangular feet (5mm), debossed monospace
    'earbox'. Ventilation = clean rounded-triangle QUINCONCE grids (explicit
    polygons, not RegularPolygon/glyphs -> fixes v2 hearts/stars): 5x5 facing the
    Orin fan + underside mesh. Two-part corner-post pry joint (single solids,
    nothing captive). Case 107x17 VERIFIED, 0.75 fits, foam seat, mute 16mm.
    Vents + summit + text verified by rendering the exported STL, not the sketch.
    [earbox_v3.step, earbox_v3.stl]
2026-07-21 docs(enclosure): v3 README section (monolith spec, split, print, verification)
2026-07-21 feat(enclosure): v4 perfect cube — flat top, fixed text, 45deg case seat
    114.5mm cube (+5mm feet), flat top (dropped v3 diagonal summit), debossed
    'earbox' now upright/readable, tighter rounded-triangle quincunx (5x5 fan +
    denser underside). No cable channel/clips: reSpeaker seats rotated 45deg, USB
    to the corner, cable drops inside; only a corner connector-clearance cutout +
    rim marker. Kept two-part pry joint (single solids), 107x17 VERIFIED, 0.75
    fits, foam seat, 16mm mute, triangular feet. Verified from the exported STL.
    [earbox_v4.step, earbox_v4.stl]
2026-07-21 docs: record the first live transcript (2026-07-22)
    First end-to-end live transcription: reSpeaker XVF3800 -> Jetson Orin Nano
    Super -> faster-whisper CPU int8 (small) on-device -> text, audio deleted by
    construction. Dead-signal culprit was a USB-A->USB-C adapter, fixed with a
    known-good cable. 60s audio in ~16s on CPU; improvised time references match
    the wall clock, proving live speech.
2026-07-21 fix: support Python 3.10 via tomli fallback for tomllib
    [earbox_core.py, earboxd.py]
2026-07-21 fix(orin): default capture to direct ALSA hw:0,0, not pulse default
    Under systemd there is no user session, so ALSA "default" routes through
    PulseAudio which has no runtime dir and fails with a read-only-fs symlink
    error, capturing nothing. The founder Orin's reSpeaker XVF3800 enumerates as
    card 0; capture hw:0,0 directly (2ch S16_LE/16k, ASR on ch0) as verified by
    the manual on-device test.
2026-07-21 fix(orin): default fw_device=cpu and heal missing git identity
    JetPack ships a CPU-only CTranslate2 wheel, so the example default
    fw_device=cuda crashloops with "not compiled with CUDA support". CPU int8
    small runs ~16s per 60s of audio on the Orin (under realtime), so cpu is the
    correct default; cuda is a later perf upgrade needing a JetPack-native CT2
    build.
    Also: ensure_repo() only set the git identity inside its fresh-init branch and
    skipped init entirely when .git already existed, so a memory repo inited
    without an identity made every transcript commit die with "Author identity
    unknown". Set identity unconditionally (idempotent) so an existing repo self-heals.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
    [earbox_core.py]
2026-07-22 fix(stt): reject hallucinations on silence
    STT invented subtitle-ghost text on quiet audio (Laurent day-4 eval: ~88%
    of daily lines were false on a sleeping room). Gate the faster-whisper path:
    condition_on_previous_text=False, temperature=0, no_speech/logprob/compression
    thresholds, tighter VAD params, and hallucination_silence_threshold when the
    installed fw supports it. Post-transcription, drop segments over no_speech_prob,
    under avg_logprob, matching the editable common/hallucinations.txt blacklist,
    near-empty, or a single repeated token; collapse phrase repetition loops. All
    thresholds are config-driven in orin.toml. Adds a stdlib unit test.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
    [earbox_core.py]
2026-07-22 feat(orin): run orind from the earbox user's repo clone for sudo-free updates
    Provision now installs the live tree as the earbox user's own git clone at
    ~earbox/earbox with an earbox-owned venv inside it, and points /opt/earbox at
    it via a symlink so the systemd unit paths (/opt/earbox/orin/orind.py,
    /opt/earbox/venv/bin/python3) resolve into the user tree unchanged. Code and
    pip updates no longer need root: `git pull` + kill the daemon PID (the unit
    already has Restart=always). Adds an earbox-restart helper and documents the
    sudo-free update flow plus the one-time root migration for boxes still on the
    old /opt copy.
2026-07-22 fix(orin): harden XVF3800 downmix against USB capture contention
    arecord can exit 0 leaving a header-only .multi.wav when a desktop PulseAudio/PipeWire session momentarily re-grabs the USB array; ffmpeg then failed with a cryptic "No such file or directory" (exit 1) that the daemon swallowed as a bare CalledProcessError. Guard the raw file (missing/<=44 bytes) with a clear error, surface ffmpeg stderr on failure, use -nostdin, and switch the single-in/single-out channel select from -filter_complex to the idiomatic -af pan=mono|c0=cN.
2026-07-23 feat: turbo/bun monorepo + transcript-monitoring UI (#1)
    * chore: scaffold turbo/bun monorepo with shared config package
    Adds the root Turbo + bun workspace layout and @choucroute/config, a vendored
    mirror of Stage's @stage-labs/config (strict type-checked eslint, single quotes,
    banned comments, 400-line/100-line caps, shared tsconfig base, madge). The
    choucroute CLI drives lint/typecheck/madge across workspaces. Python firmware and
    hardware dirs are left untouched and excluded from linting.
    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
2026-07-24 feat: fly audio-ingest streaming API + box streamer (#2)
    * feat: fly audio-ingest streaming API + box streamer
    Adds apps/ingest, a small Bun WebSocket server deployed on Fly (region sin)
    that accepts the box's live PCM S16LE 16k mono stream and fans it out to
    browser subscribers, with a clean AudioSink seam where cloud STT attaches next.
    - WS /ingest: publisher (box) streams raw PCM binary frames; server tracks
    stats (bytes/samples/audio-vs-wall seconds/gaps), sends periodic acks, keeps
    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
2026-07-24 fix(orin): stop garbling live audio from an odd device channel count
    The live stream sounded like harsh digital buzz because ffmpeg was told the
    capture had a fixed channel count (-f s16le -ac <channels>) while the XVF3800
    actually presents a different (odd) channel count: a processed ASR channel plus
    a silent reference channel. With the wrong -ac, ffmpeg mis-framed the
    interleaved PCM and folded the silent channel into the mono output on every 3rd
    sample, adding a ~5.3 kHz buzz over the real (quiet, correct) audio.
    Evidence from a live /subscribe capture: every 3rd int16 sample is exactly 0
    (zero-fraction 0.375, hard period-3), byte offset 0 is the correct alignment
    (so it is not a chunkin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
